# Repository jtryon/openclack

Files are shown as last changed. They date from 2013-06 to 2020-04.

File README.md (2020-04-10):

# OpenClack.TKL

## Preface
This repository contains all the source files needed to create a 87 key (tenkeyless) mechanical keyboard.</br>
In order to actually build this keep in mind you'll need access to the following.
* PCB fabrication.
* CNC, laser or waterjet cutting.
* Soldering iron and supplies.
* A source for your switches, stabilizers and electronic components.

## Licensing
Software in this project is licensed under the GPL.  See GPL.md</br>
Hardware in this project is licensed under the TAPR.  See TAPR.md

## Details
* Tenkeyless layout.
* Compatible with Cherry MX switches and both Cherry and Costar stabilizers.
* LED support for each key.
* Does not require a resistor for each LED.
* N-Key roll-over, no ghosting, 1 diode per switch.
* Firmware which allows for custom key mapping, macros, de-bouncing and LED control.
* Mini-B connector.
* Teensy 2.0++ controller.
Some images of a completed prototype based on the designs in this repo are in the "prototype_images" folder.
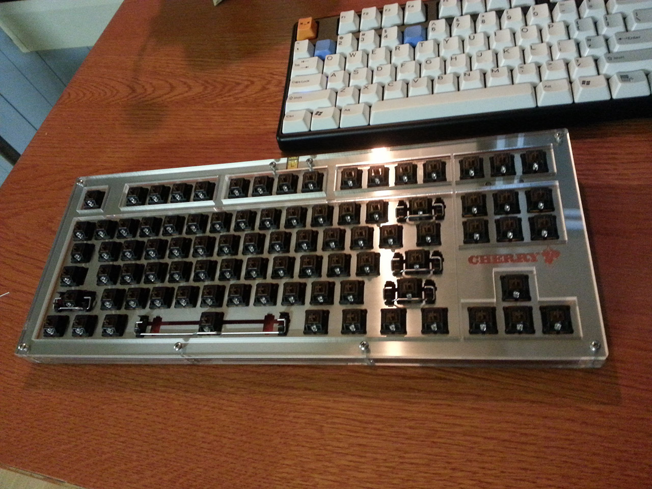
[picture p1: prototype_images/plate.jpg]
Plate
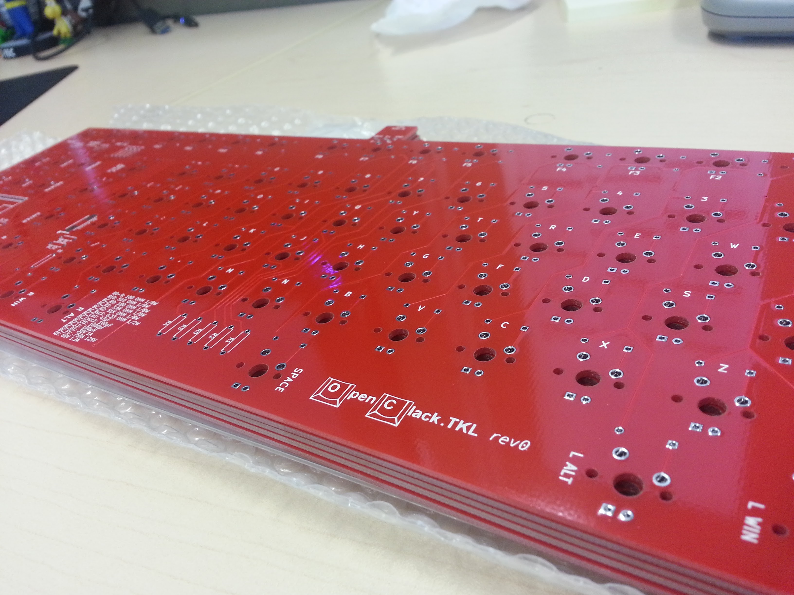
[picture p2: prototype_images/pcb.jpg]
PCB


## Project Files
* /dashkey/* - Firmware for the keyboard, codenamed DashKey.  Coded by SiberX.
* /fabrication/* - Final project files to be sent off and fabricated.
* /kicad_files/* - Kicad project.  Open the file "openclack-tkl.pro".
* /notes/* - Notes explaining the LED configuration, parts list, info on the boost converter, resistors.
* openclack.skp - Rough 3D render of the project (SketchUp).

## Instructions
There's currently no guide on how to do this but if you're technically inclined it should be doable with all the files contained herein.  If someone wants to develop a guide feel free to contribute!

## Loading Firmware
WIP

## Sources/Thanks
Thanks to the folks at http://deskthority.net/ for helping out when I had questions about measurements!</br>
Also a big thanks to BathroomEpiphanies.  Wouldn't have been able to do it without your amazing wiki.  [Check it out here!](http://deskthority.net/wiki/KiCAD_keyboard_PCB_design_guide)

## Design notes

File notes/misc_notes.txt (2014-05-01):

####Misc:

- Inserts - https://www.acklandsgrainger.com/AGIPortalWeb/WebSource/ProductDisplay/globalProductDetailDisplay.do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
 - Length: 3/16"
 - Drill Size: 3/16"
 - Thread Size: 4-40
- Screws - Up to you.  I'd recommend 4-40, Phillips countersunk.  You'd need to countersink the acrylic though (don't crack it!).
 - All screw holes are 0.2355" from edge (corner, center of intersecting lines) of case and are 0.045" in radius.
 - All insert holes are 0.2355" from edge (corner, center of intersecting lines) of case and are 0.0625" in radius.
- Layer cake style case notes (check out 3D_mockup.skp for a better idea of this)
 - 9mm for spacer
 - 1.524mm for plate
 - 10.524mm together
 - 5.0038mm from the top of the plate to the top of the pcb
 - 5.5202mm left
 - 1.66mm pcb
 - 3.8602mm clearance below pcb

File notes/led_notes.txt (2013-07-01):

10 sets of 8 leds each in series
1 odd set with 7 leds in series

power via boost converter and related componenents

http://hobby-hour.com/electronics/ledcalc.php
http://www.nomad.ee/micros/mc34063a/

teensy 2.0++ typical current draw 60.2 mA
boost converter efficiency is aprox 80%+

LED CALC Results (8 series):
Calculated resistance:	200O
Nearest lower 5% resistor:	180O
Nearest higher 5% resistor:	200O**
Power dissipated by the resistor:	9.8 mW
Recommended resistor Wattage:	1/8 W
Power consumed by the LEDs (PLED):	123.2 mW
Total power consumption (PTotal):	133 mW
Efficiency (PLED/PTotal) x 100 :	92.63 %

LED CALC Results (7 series):
Calculated resistance:	514.29O
Nearest lower 5% resistor:	510O*
Nearest higher 5% resistor:	560O
Power dissipated by the resistor:	25.2 mW
Recommended resistor Wattage:	1/8 W
Power consumed by the LEDs (PLED):	107.8 mW
Total power consumption (PTotal):	133 mW
Efficiency (PLED/PTotal) x 100 :	81.05 %

LED CALC Results (individual indicator LEDs):
Calculated resistance:	2.8kO
Nearest lower 5% resistor:	2.7kO*
Nearest higher 5% resistor:	3kO
Power dissipated by the resistor:	2.8 mW
Recommended resistor Wattage:	1/8 W
Power consumed by the LED (PLED):	2.2 mW
Total power consumption (PTotal):	5 mW
Efficiency (PLED/PTotal) x 100 :	44 %

MC34063A CALC Results:
Ct=626 pF		(above 700 pf cap)
Ipk=773 mA
Rsc=0.388 Ohm   (rsc<= 0.3 Ohm resistor, 1/4 watt resistor)
Lmin=81 uH      (minimum inductor, 100mh)
Co=39 uF		(47 mf cap for here, supports 25v+)
R=180 Ohm
R1=3.6k R2=51k (18.96V)
http://i.imgur.com/qerIIto.png
1N5818, 1N5819 schottky diode
//All otherwise unmentioned resistors can be 1/8th watt//

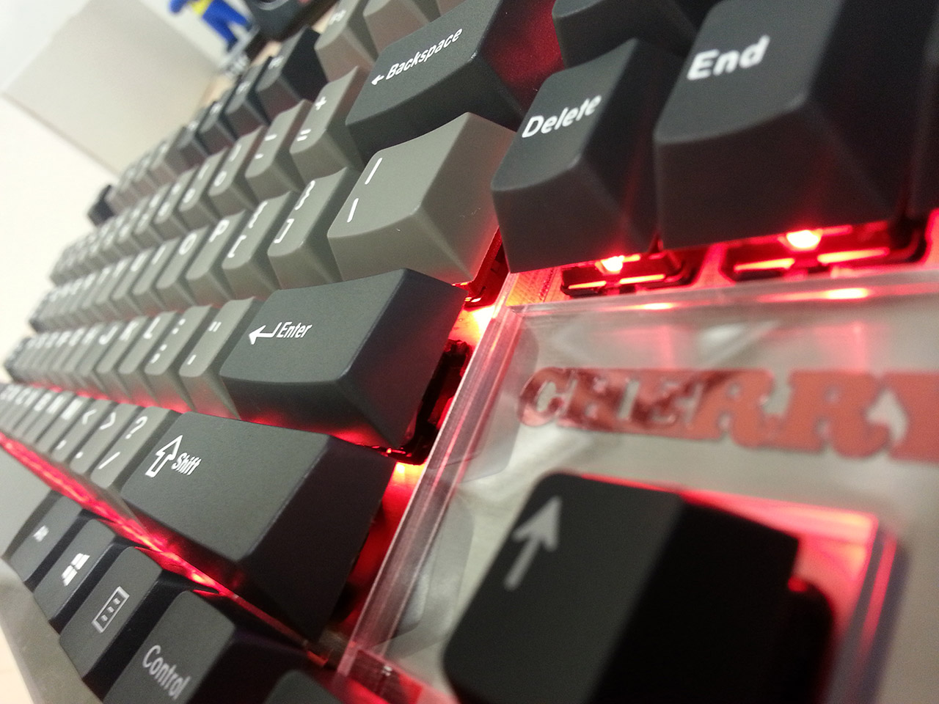
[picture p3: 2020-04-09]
prototype_images/closeup.jpg

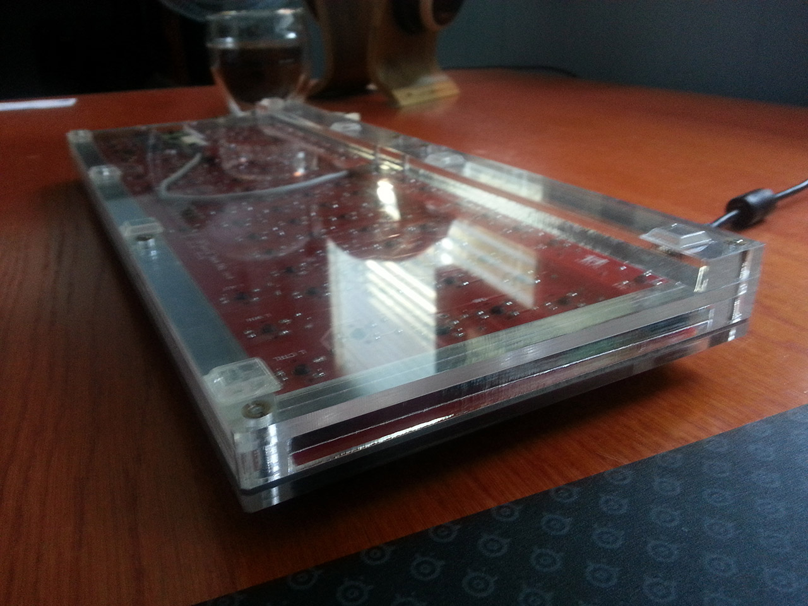
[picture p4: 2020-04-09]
prototype_images/acrylic_back.jpg

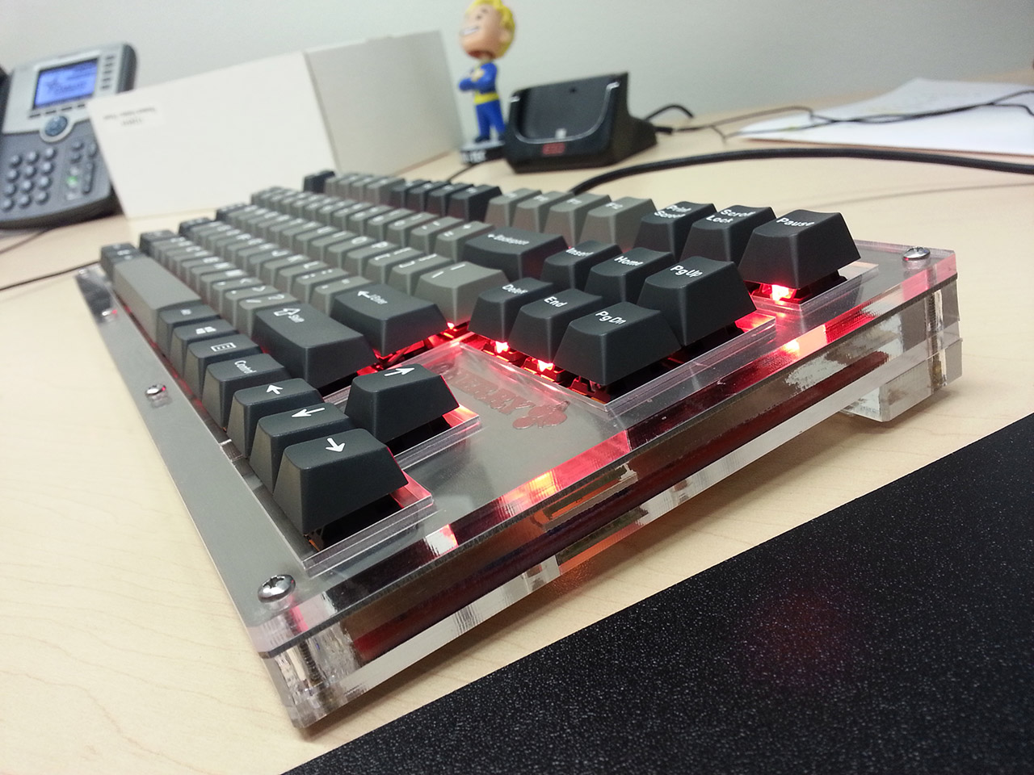
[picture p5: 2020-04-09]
prototype_images/acrylic_top.jpg

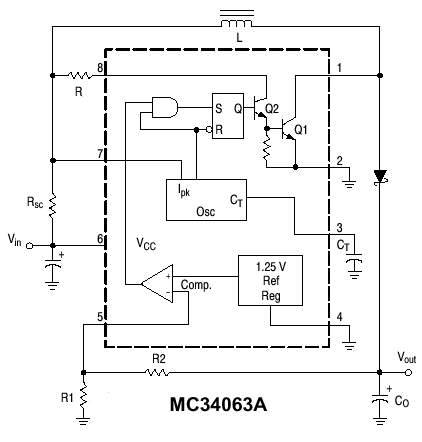
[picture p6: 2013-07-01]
notes/MC34063A_diagram.png

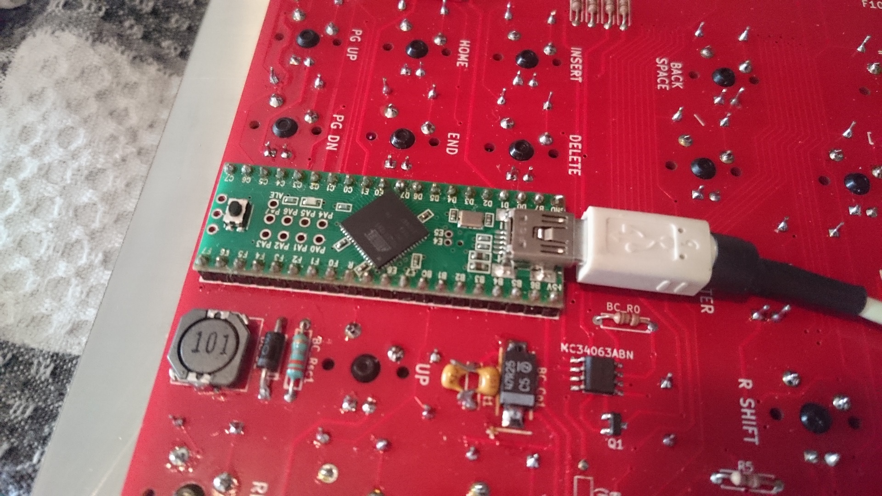
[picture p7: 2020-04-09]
prototype_images/teensy1.JPG

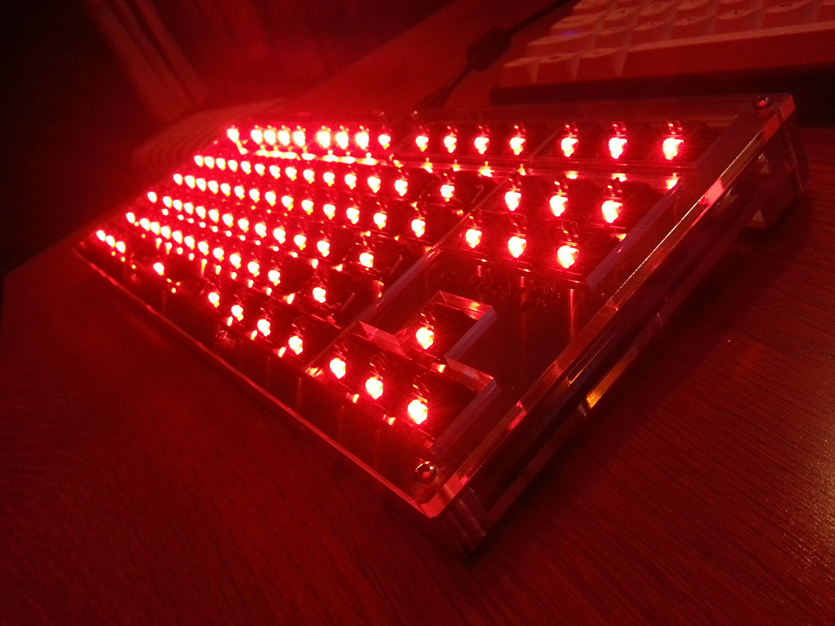
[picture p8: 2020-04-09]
prototype_images/leds.jpg

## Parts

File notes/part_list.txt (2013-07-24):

Quantity Sug.		Okay?		KiCad Module			Kicad Ref				URL																						Thickness	Kicad Footprint
=============================================================================================================================================================================================================================
1					Y			BC_Co1					CP1						http://www.digikey.ca/product-detail/en/TR3D476K025C0150/718-1525-1-ND/1860000          3.10mm		TantalC_SizeD_EIA-7343_HandSoldering_RevA_28Aug2012
1					Y			BC_Ct1					CP1						http://www.digikey.ca/product-detail/en/C410C102K1R5TA7200/399-4450-1-ND/818307         2.54mm      CP_6mm
1					Y			BC_Cvcc1				CP1						http://www.digikey.ca/product-detail/en/RVA0J101MNG/493-6670-1-ND/3465996               3.00mm      TantalC_SizeD_EIA-7343_HandSoldering_RevA_28Aug2012
1					Y			BC_L1					INDUCTOR				http://www.digikey.ca/product-detail/en/SCRH103R-101/595-1406-1-ND/2771443              3.10mm      SCRH103R
1					Y			BC_R0					RESISTOR				http://www.digikey.ca/product-detail/en/CF18JT180R/CF18JT180RCT-ND/2022724              1.70mm 		R3
1					Y			BC_R1					RESISTOR				http://www.digikey.ca/product-detail/en/CF18JT3K60/CF18JT3K60CT-ND/2022755              1.70mm      R3
1					Y			BC_R2					RESISTOR				http://www.digikey.ca/product-detail/en/CF18JT51K0/CF18JT51K0CT-ND/2022783              1.70mm      R3
1					Y			BC_Rsc1					RESISTOR				http://www.digikey.ca/product-detail/en/1622602-1/A105966CT-ND/3477549                  2.30mm      R4
1					Y			BC_D1					DIODE					http://www.digikey.ca/product-detail/en/1N5818-T/1N5818DICT-ND/190657                   2.72mm      DO-41
1					Y			VREG1					MC34063ABN				http://www.digikey.ca/product-detail/en/MC34063ACD-TR/497-7850-1-ND/1883654             1.75mm      so-8
1					Y			Q1						FET_N					http://www.digikey.ca/product-detail/en/IRLML2060TRPBF/IRLML2060TRPBFCT-ND/2271917		1.12mm      SOT23
2 (1 backup)		Y			BC_F1					FUSE					http://www.digikey.ca/product-detail/en/0251.750MXL/F2353-ND/776753						3.18mm		MQ750 (double check size)
100					Y			D						DIODE(is an LED tho)	http://www.digikey.ca/product-detail/en/OVLBR4C7/365-1175-ND/827111									Part of the switches
100					Y			Dx:x					DIODE					http://www.digikey.ca/product-detail/en/1N4148,113/568-1360-1-ND/763357								D3
10					Y			R0-9					RESISTOR				http://www.digikey.ca/product-detail/en/CF18JT180R/CF18JT180RCT-ND/2022724							R3
1					Y			R10						RESISTOR				http://www.digikey.ca/product-detail/en/CF18JT510R/CF18JT510RCT-ND/2022735							R3
4					Y			D0,D1					LED						http://www.digikey.ca/product-detail/en/OVLBY4C7/365-1176-ND/827112									LED-3MM
2					Y			LED_R0,LED_R1			RESISTOR				http://www.digikey.ca/product-detail/en/CF18JT2K70/CF18JT2K70CT-ND/2022752							R3
1					Y			USB-MINI-B				CON1					http://www.digikey.ca/product-detail/en/USB-M26FTR/ED2992CT-ND/2677756								conn_usb_B_mini_smd
4					Y			N/A						N/A						http://www.digikey.ca/product-detail/en/PRPC040SAAN-RC/S1011EC-40-ND/2775214

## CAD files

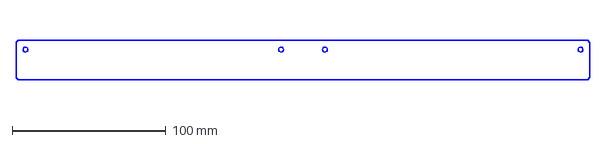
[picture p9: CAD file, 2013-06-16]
dxf_plots/acrylic_4.dxf
373.0 x 25.4 mm

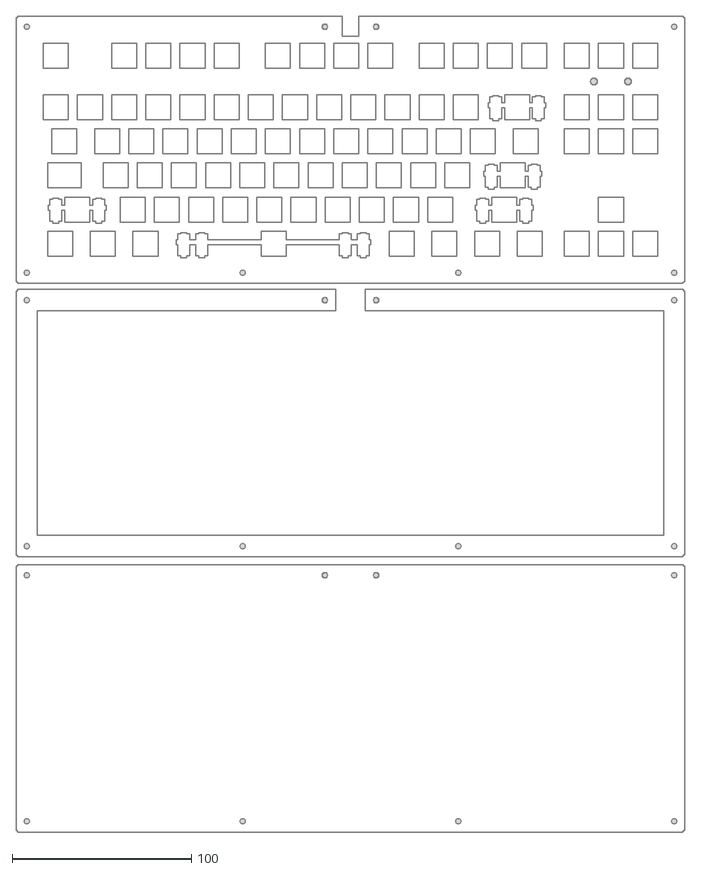
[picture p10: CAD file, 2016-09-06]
fabrication/prototype b/openclack-tkl-case-and-plate.dxf
373.0 x 455.0

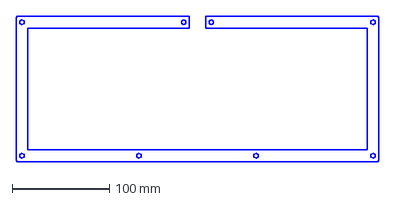
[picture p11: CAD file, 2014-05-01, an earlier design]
fabrication/prototype a/case/acrylic_1.dxf
373.0 x 149.1 mm

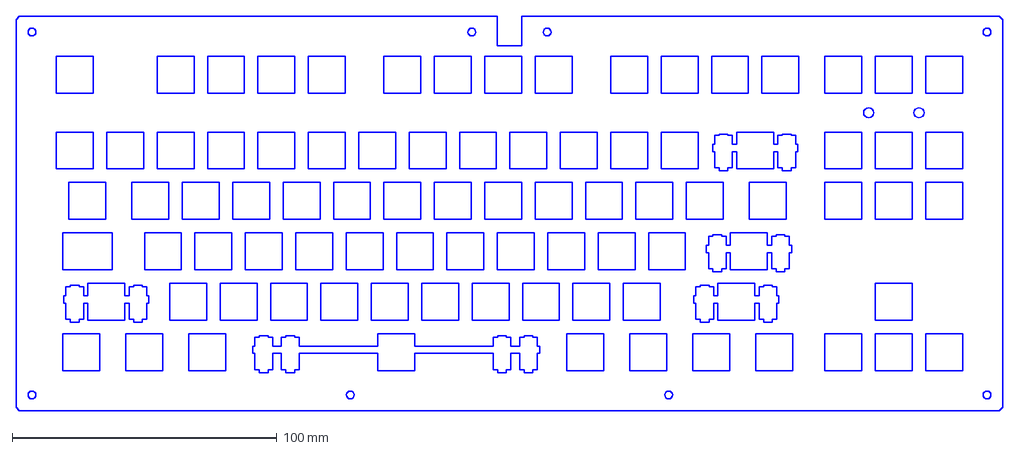
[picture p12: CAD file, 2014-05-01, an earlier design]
fabrication/prototype a/plate/plate.dxf
373.0 x 149.1 mm

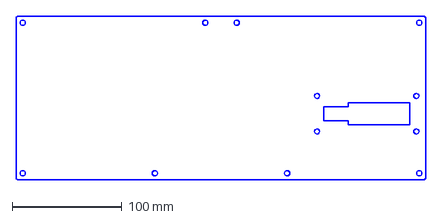
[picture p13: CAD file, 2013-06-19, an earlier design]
fabrication/prototype a/case/acrylic_2.dxf
373.0 x 149.1 mm

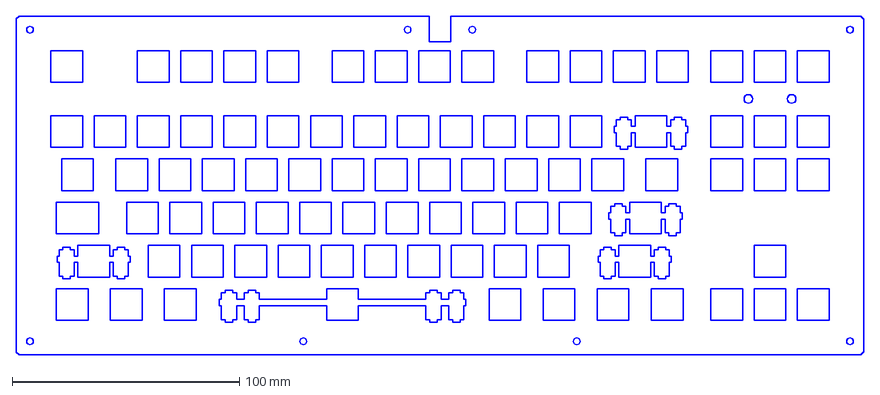
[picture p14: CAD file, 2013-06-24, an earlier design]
fabrication/prototype a/plate/plate_modded_4_waterjet_cut.dxf
373.0 x 149.1 mm

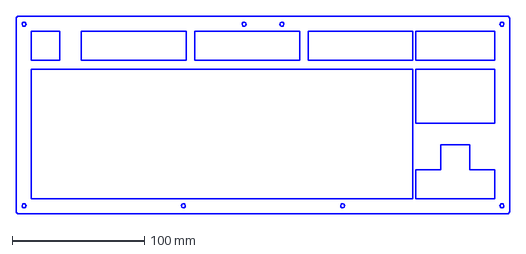
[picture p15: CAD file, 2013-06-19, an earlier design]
fabrication/prototype a/case/acrylic_0.dxf
373.0 x 149.1 mm

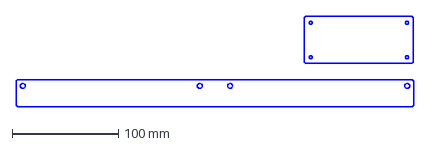
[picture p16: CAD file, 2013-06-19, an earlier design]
fabrication/prototype a/case/acrylic_3.dxf
373.0 x 84.8 mm

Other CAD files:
openclack.skp

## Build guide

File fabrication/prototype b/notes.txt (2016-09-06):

This version of the project is a simple and lightweight case you can create with a laser cutter.
All units are in mm.

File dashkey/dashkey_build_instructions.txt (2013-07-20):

1. Grab a copy of WinAVR:
http://sourceforge.net/projects/winavr/files/
And install it.

2. Grab a copy of the eclipse IDE (you should get the C/C++ edition if you want minimum grief):
http://www.eclipse.org/downloads/
Or set up another development environment of your choice

3. Get the latest avr-eclipse:
http://sourceforge.net/projects/avr-eclipse/files/avr-eclipse%20beta%20versions/
And add it to your eclipse installation. A helpful guide can be found here:
http://avr-eclipse.sourceforge.net/wiki/index.php/Plugin_Download

4. Grab the latest build of LUFA:
http://www.fourwalledcubicle.com/LUFA.php (2013-03-03 as of this writing)
And extract it to a folder.

5. Grab the latest build of dashkey out of the openclack github: (if you don't have it already)
https://github.com/toastfox/openclack

6. Open the dashkey project in eclipse

7. Edit the makefile to provide a valid LUFA_PATH. While you're in here, be sure to set valid MCU, F_CPU, etc.. values

8. Because eclipse sucks, you'll need to ignore a couple of their code analysis tools. To do so, open the project properties, go to "C/C++ General" then "Code Analysis". Set the radio button to "Use project settings", then uncheck "Symbol is not resolved", "Type cannot be resolved" and "Field cannot be resolved" down at the bottom

7. Attempt to build, cry if it fails, fix errors

8. Assuming no errors, grab the resulting dashkey.hex and flash it to your keyboard controller

9. Optionally, generate an eeprom file and flash that too (if you want a custom keyboard map)

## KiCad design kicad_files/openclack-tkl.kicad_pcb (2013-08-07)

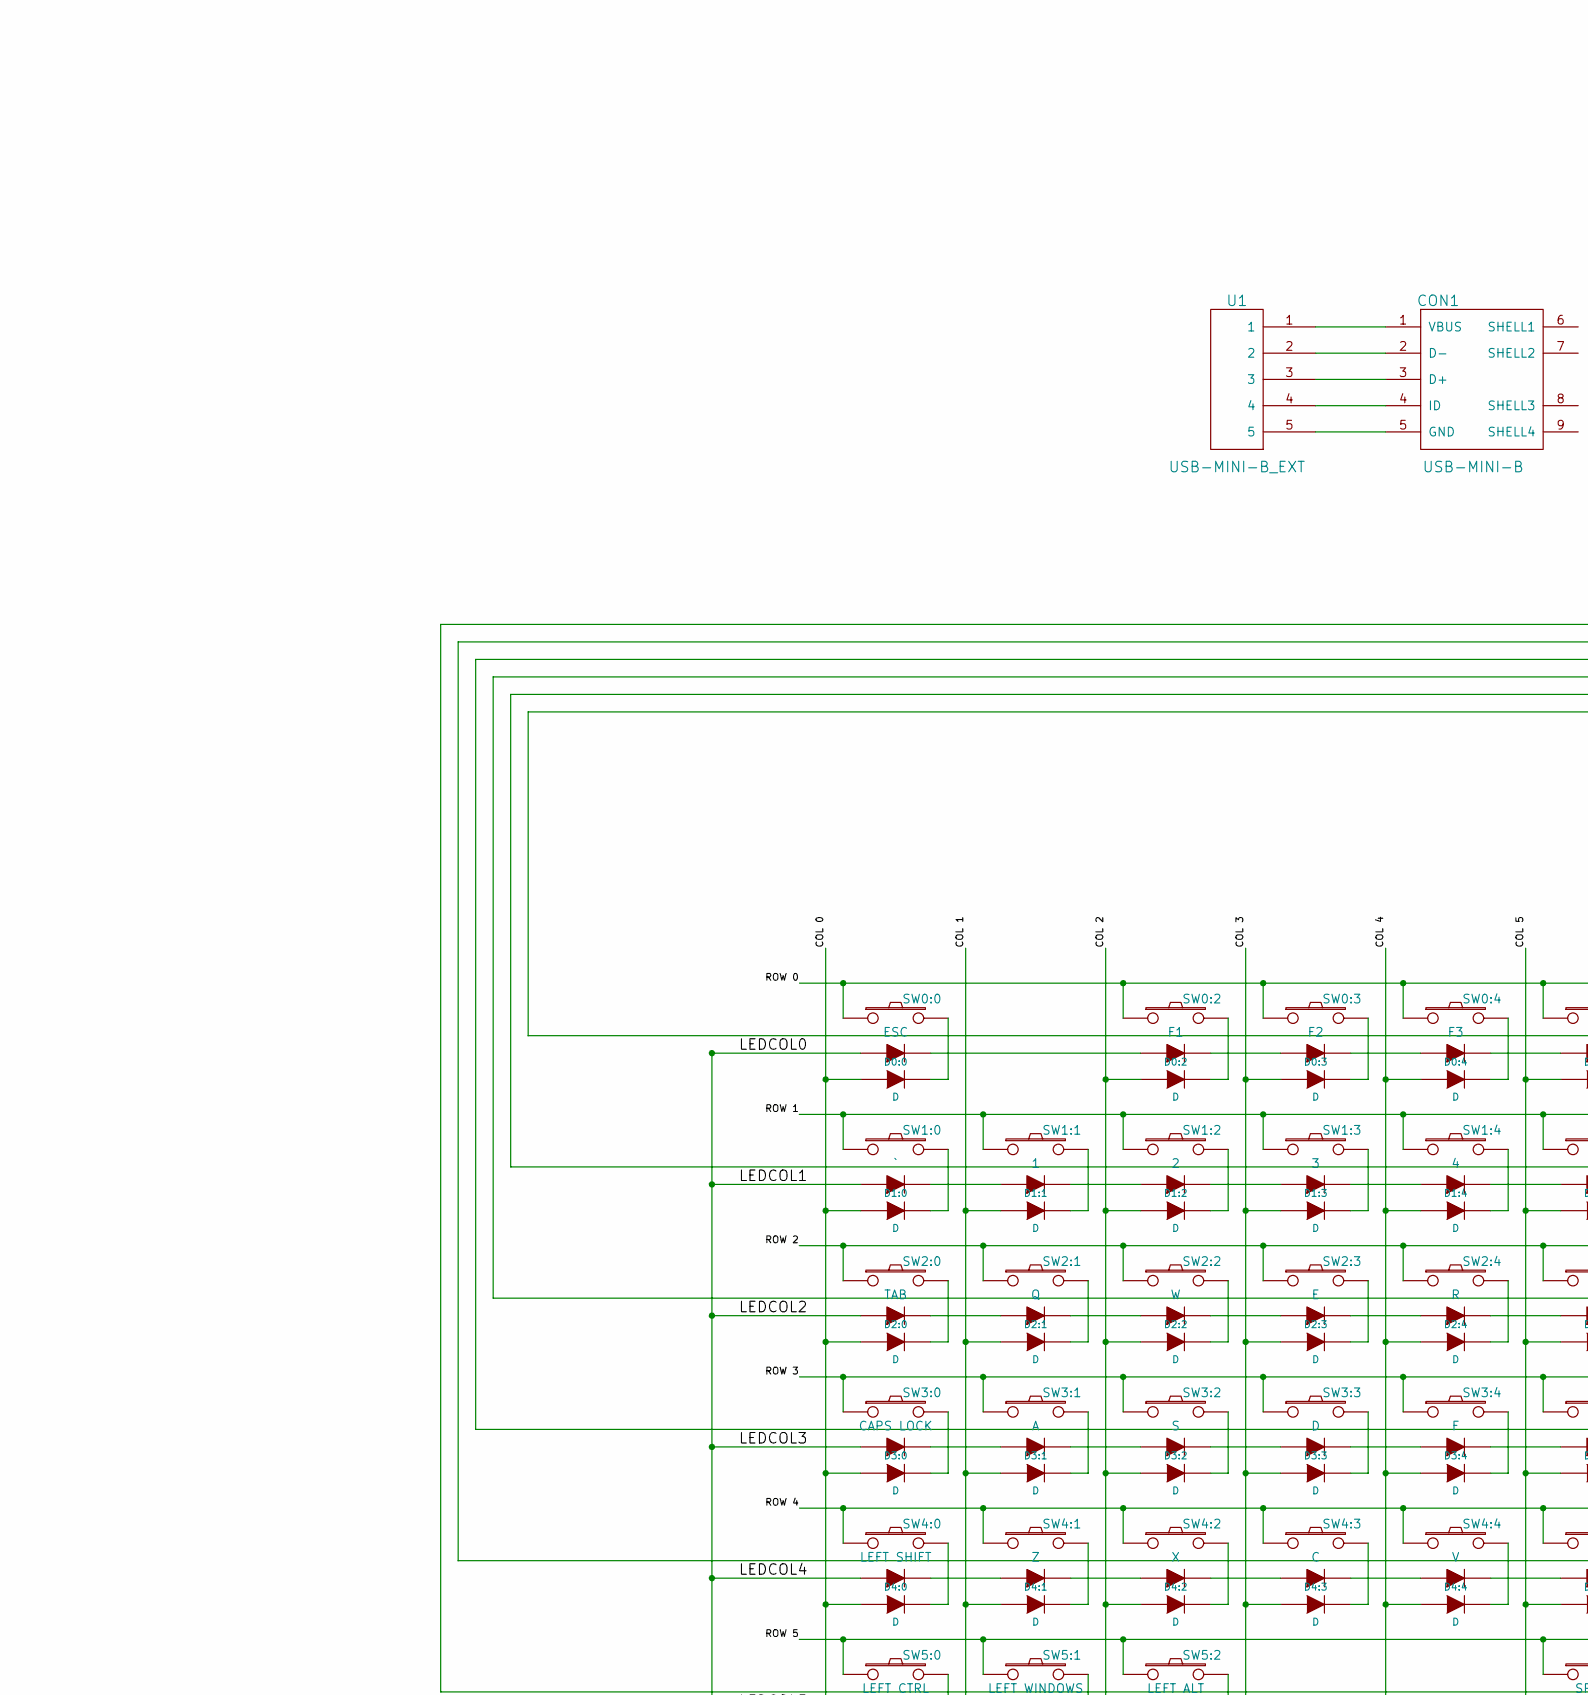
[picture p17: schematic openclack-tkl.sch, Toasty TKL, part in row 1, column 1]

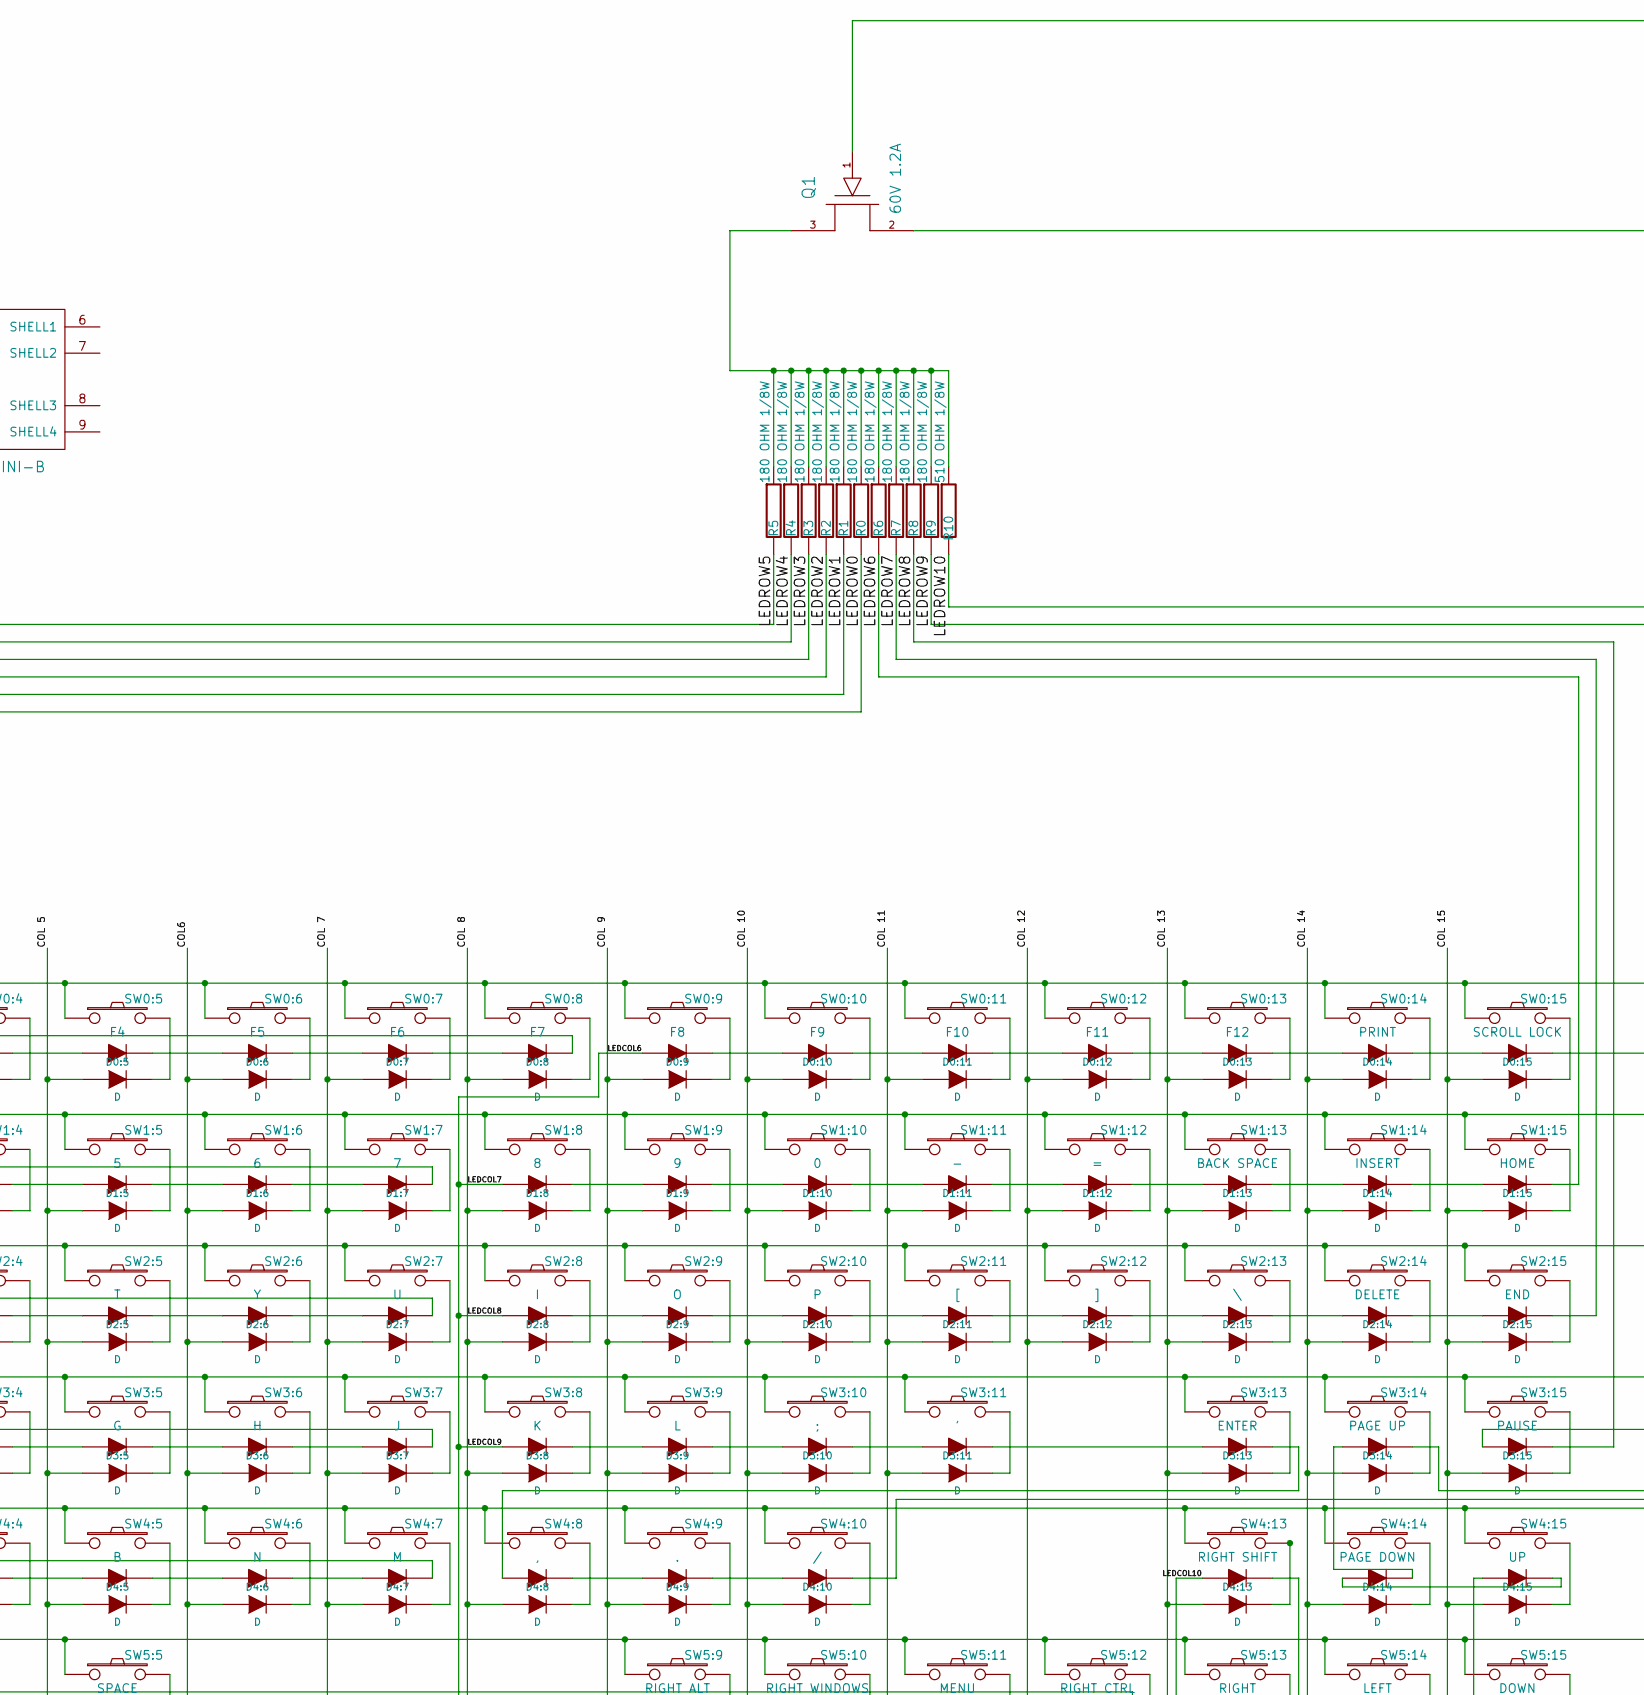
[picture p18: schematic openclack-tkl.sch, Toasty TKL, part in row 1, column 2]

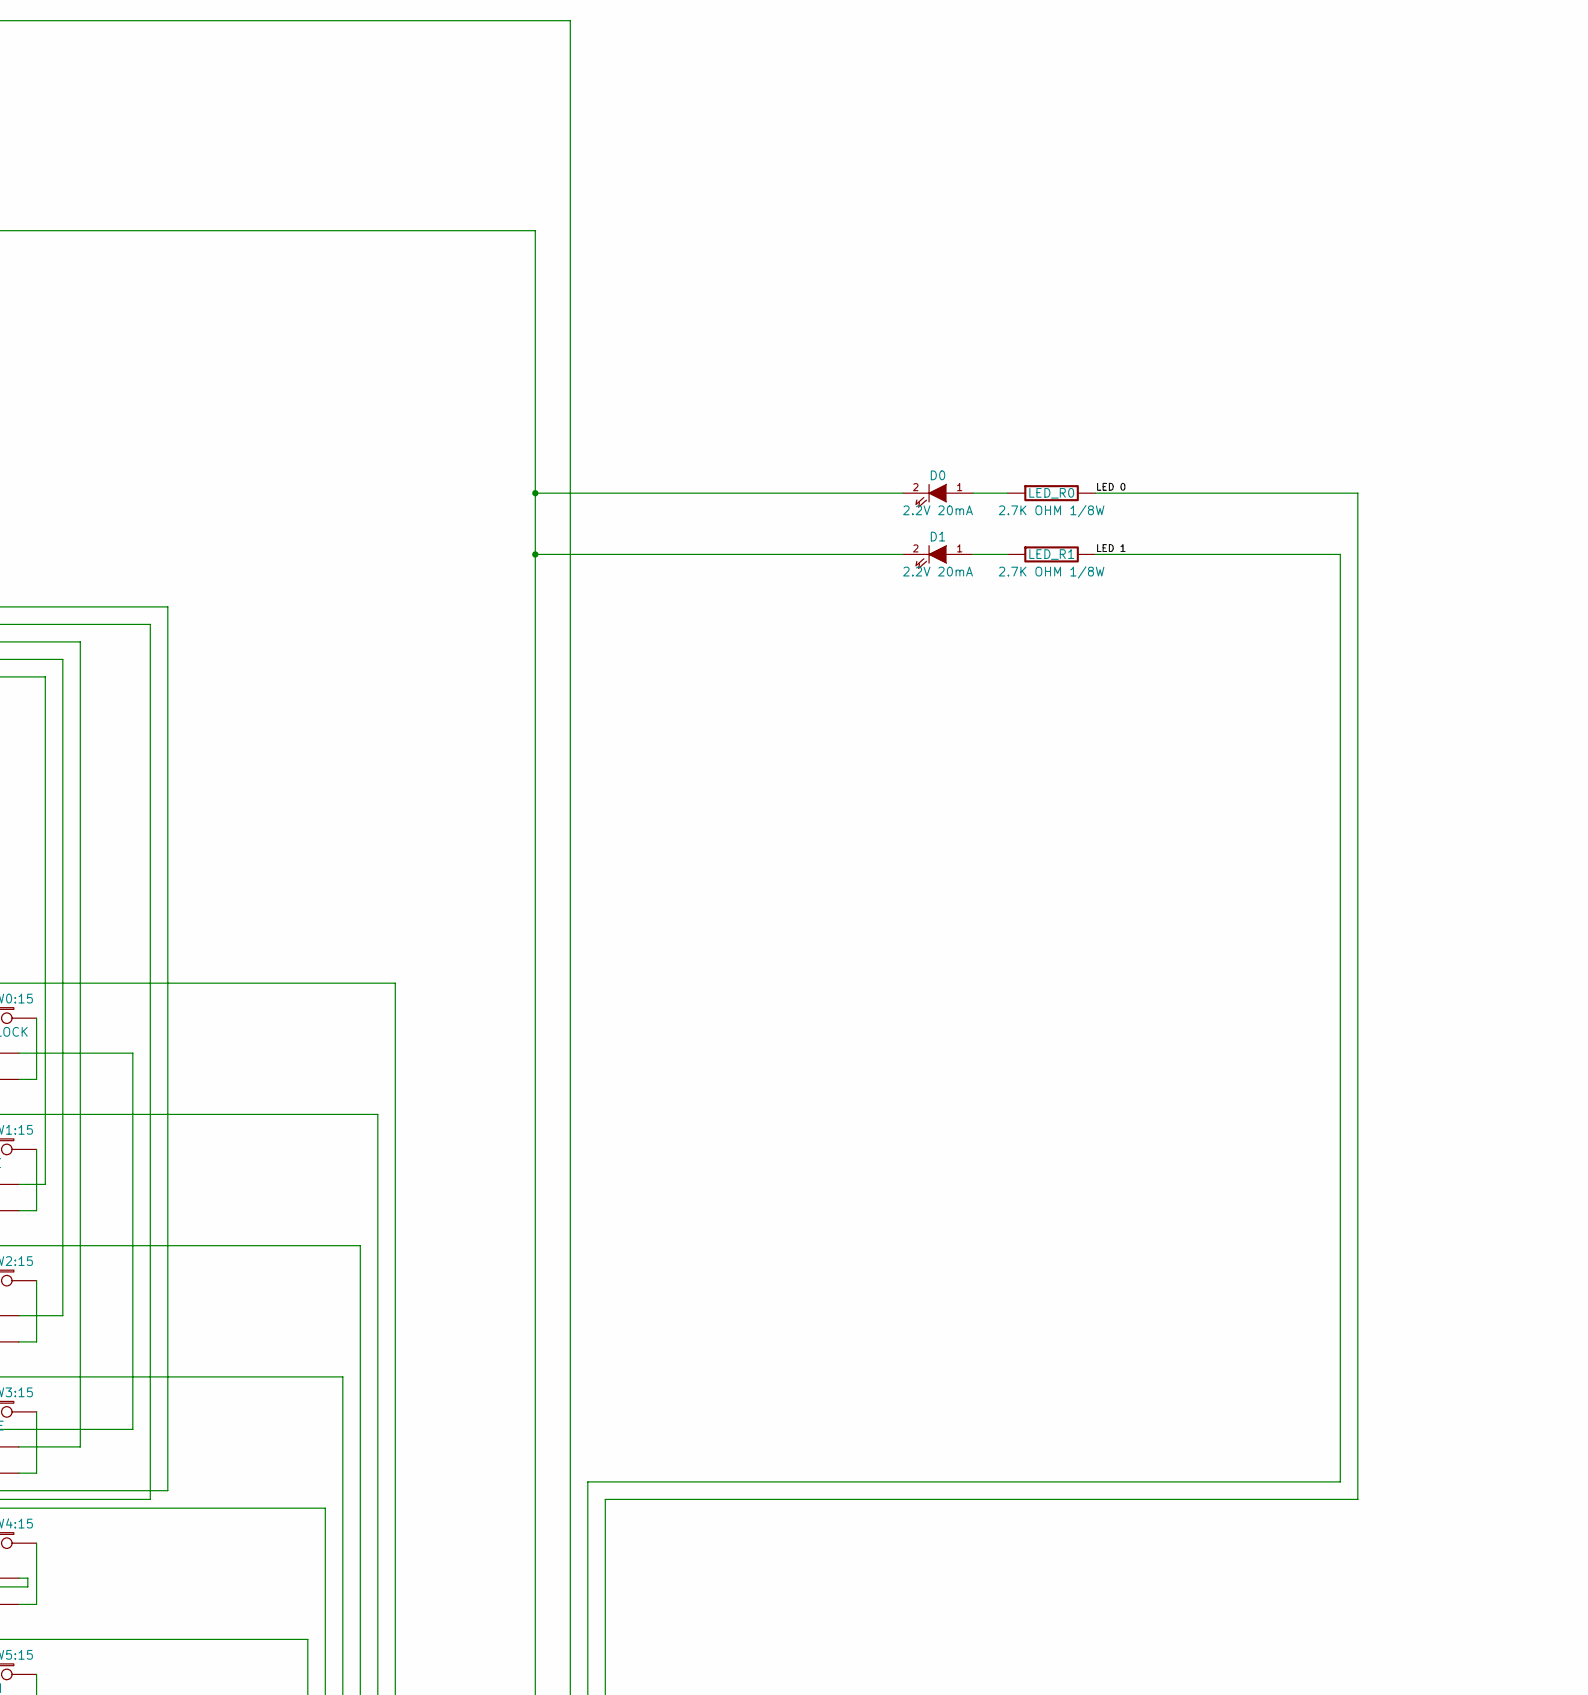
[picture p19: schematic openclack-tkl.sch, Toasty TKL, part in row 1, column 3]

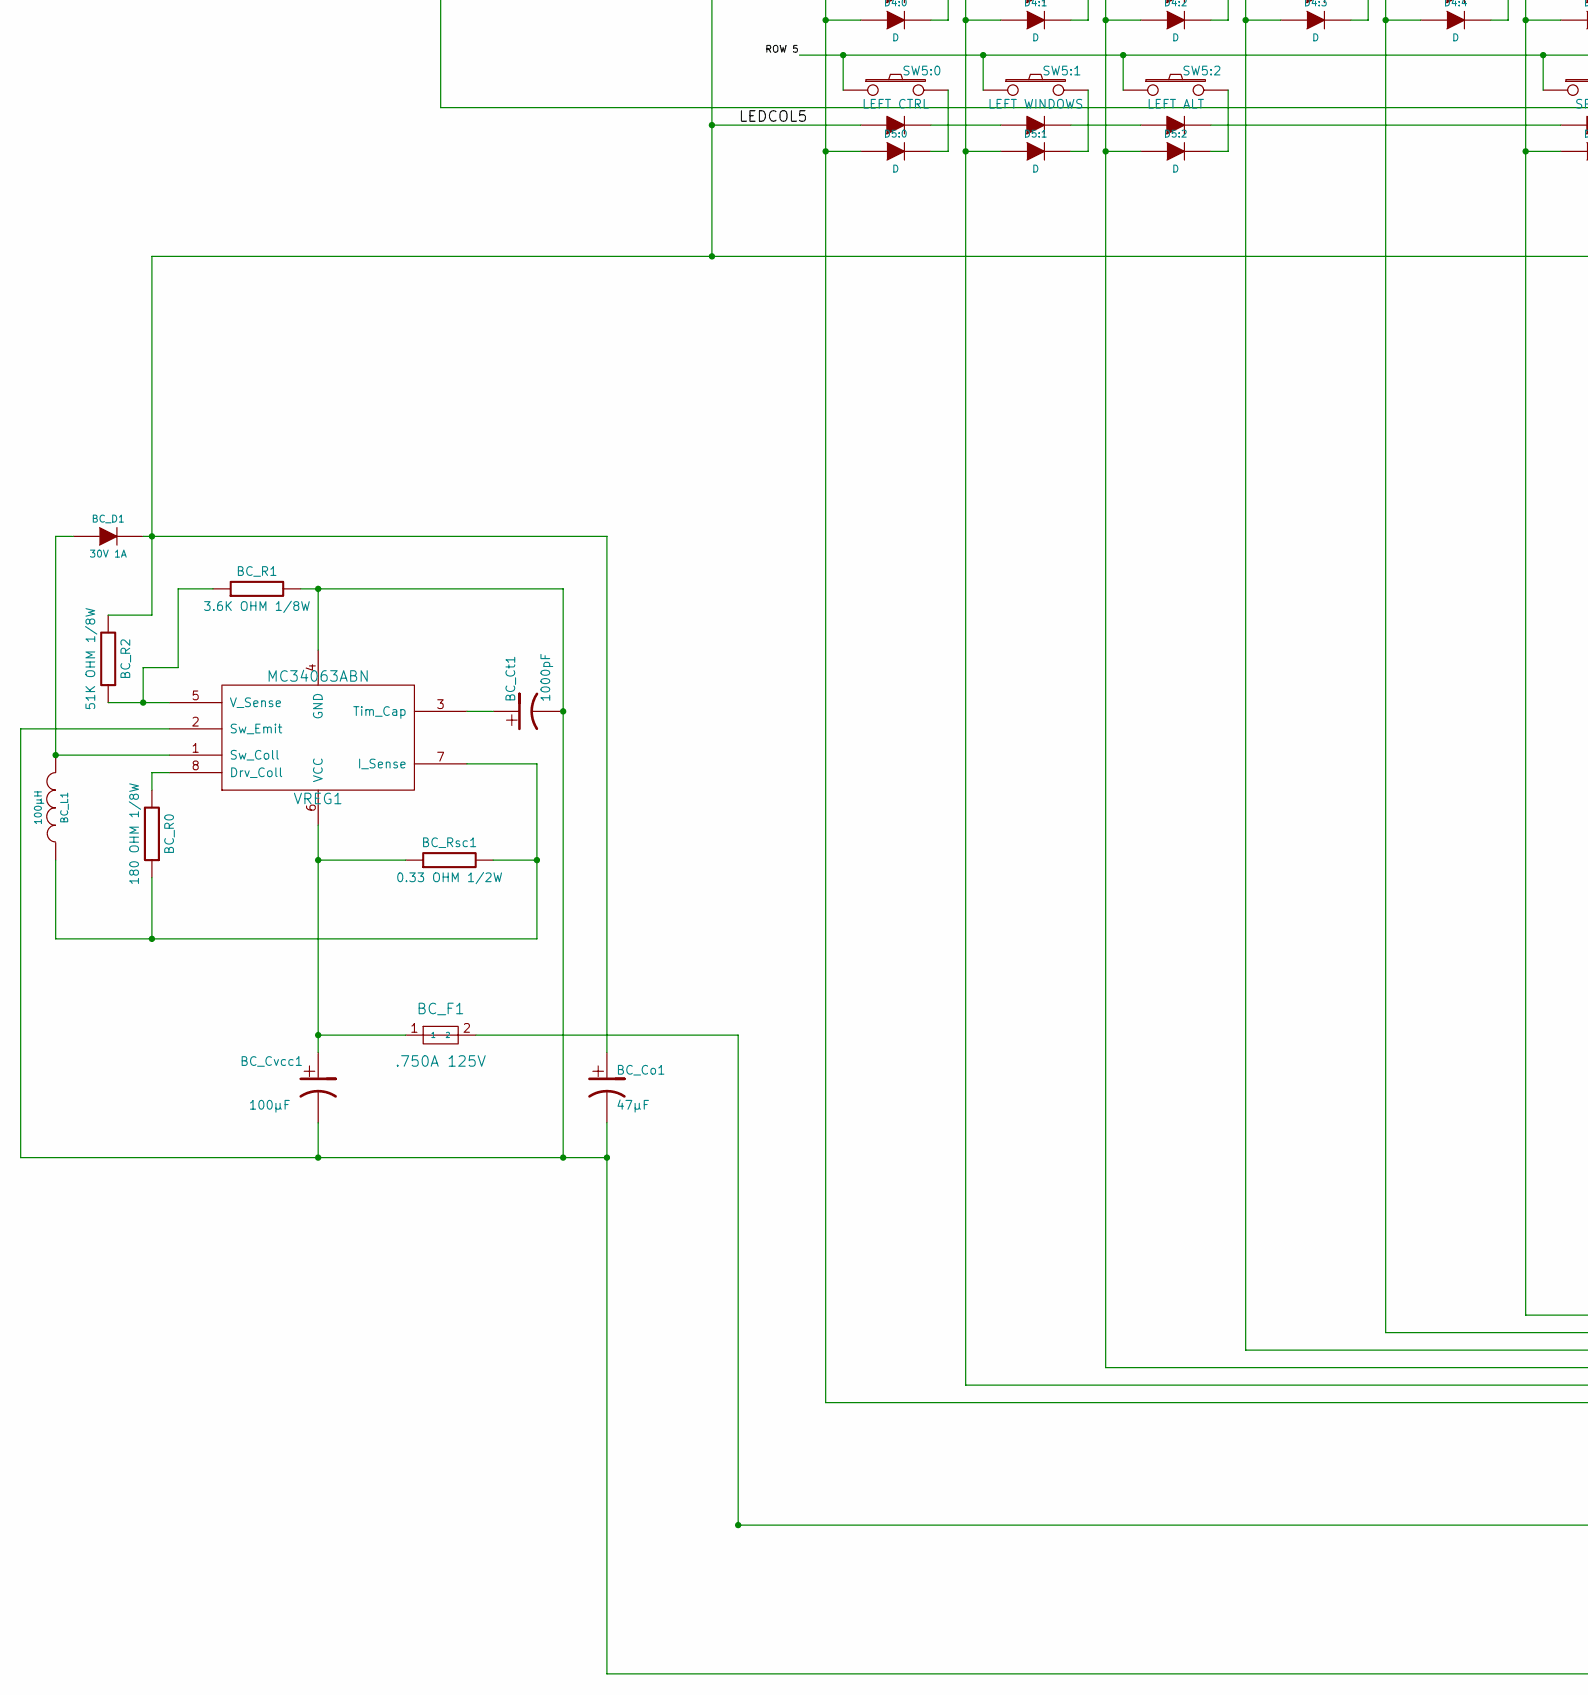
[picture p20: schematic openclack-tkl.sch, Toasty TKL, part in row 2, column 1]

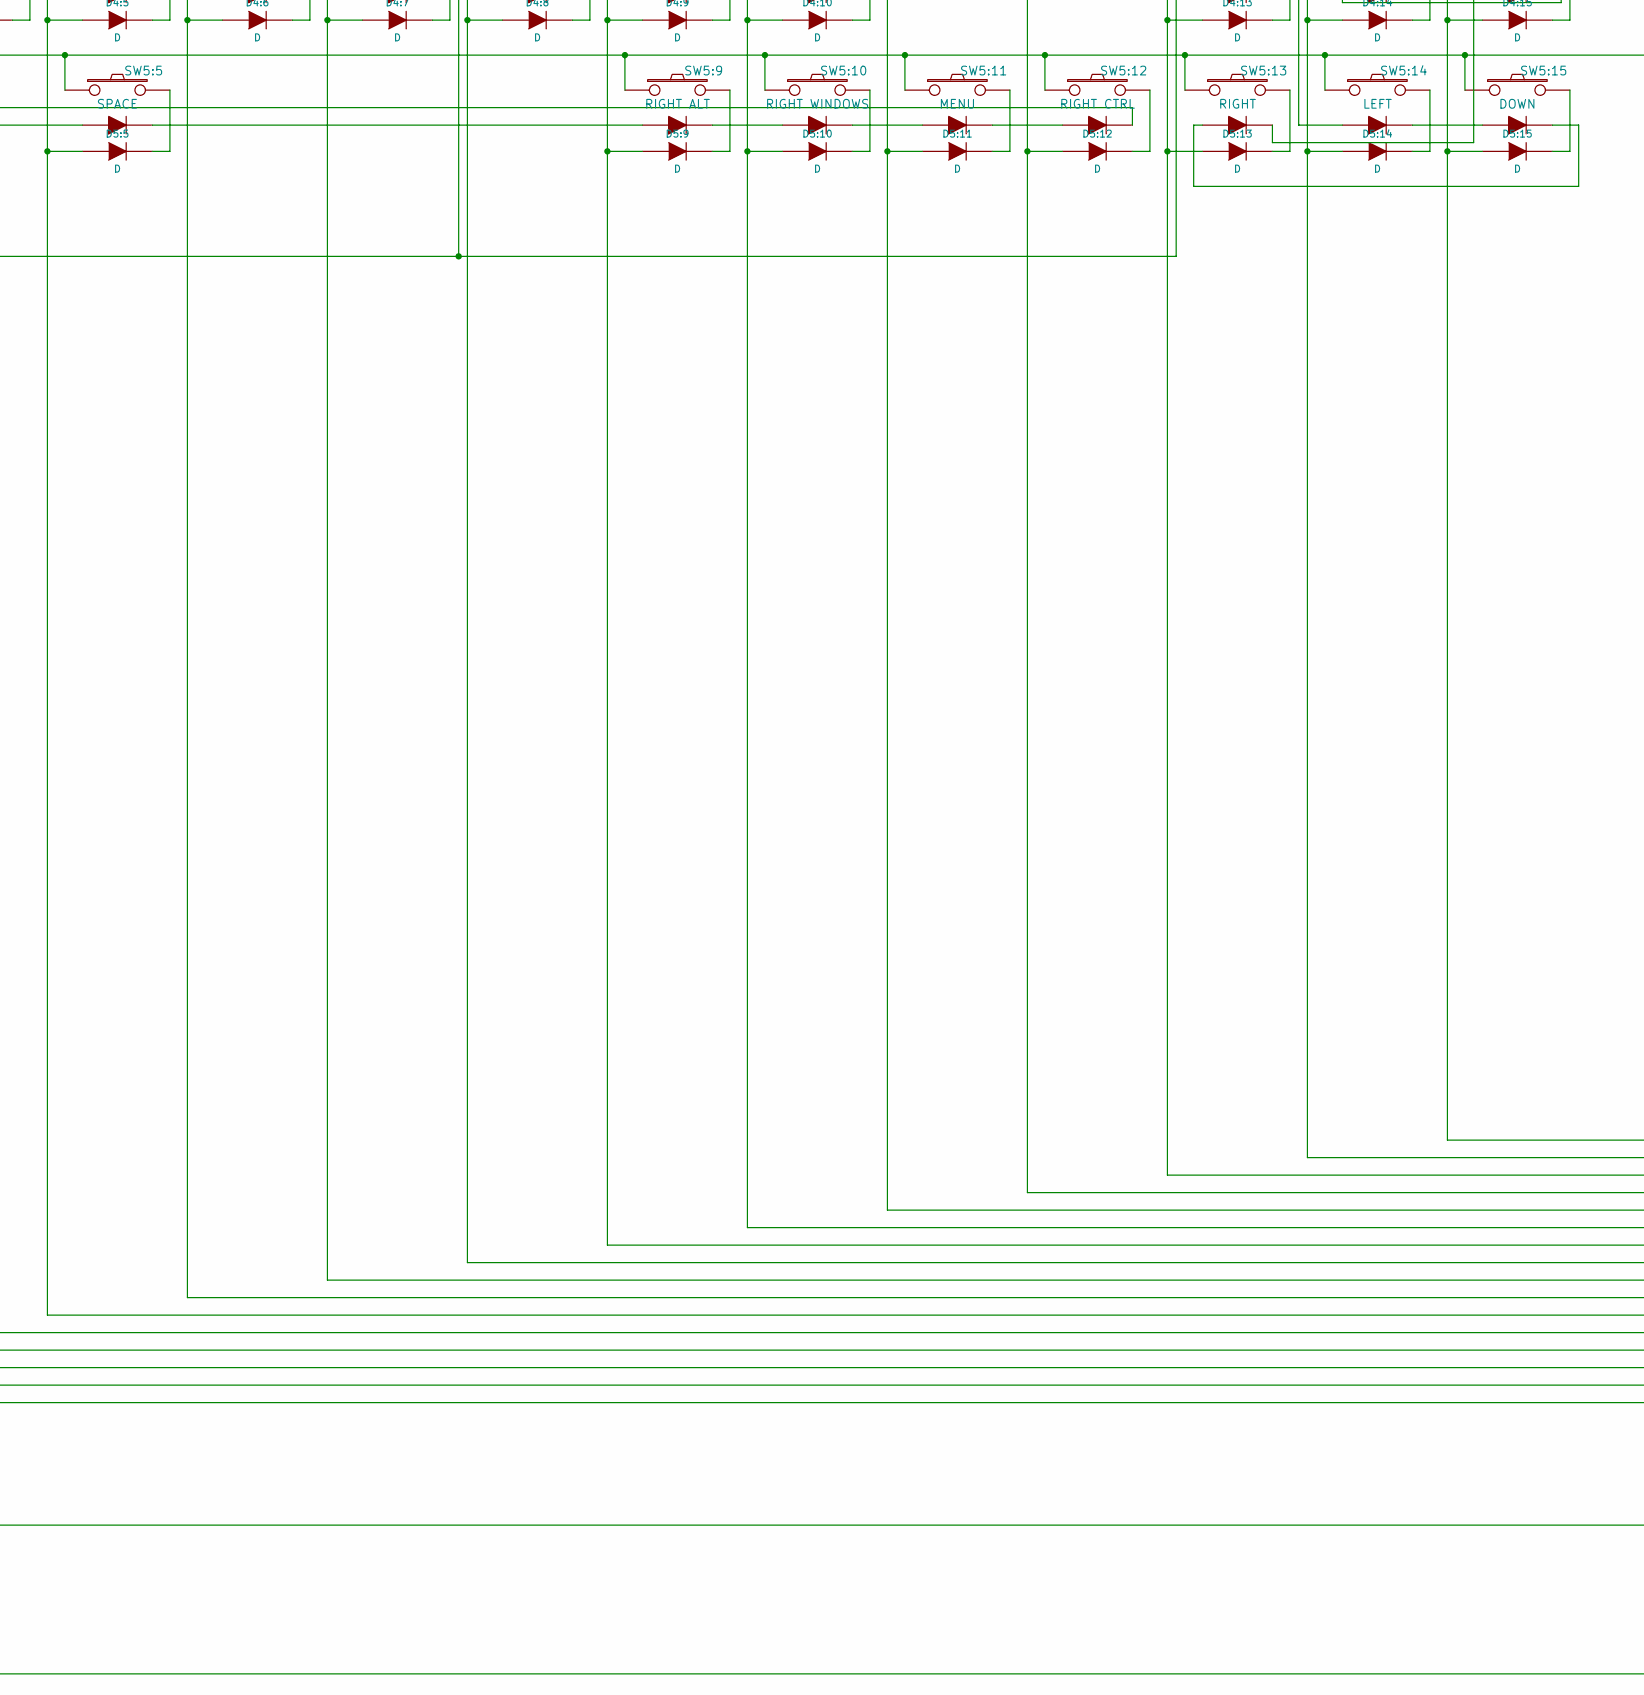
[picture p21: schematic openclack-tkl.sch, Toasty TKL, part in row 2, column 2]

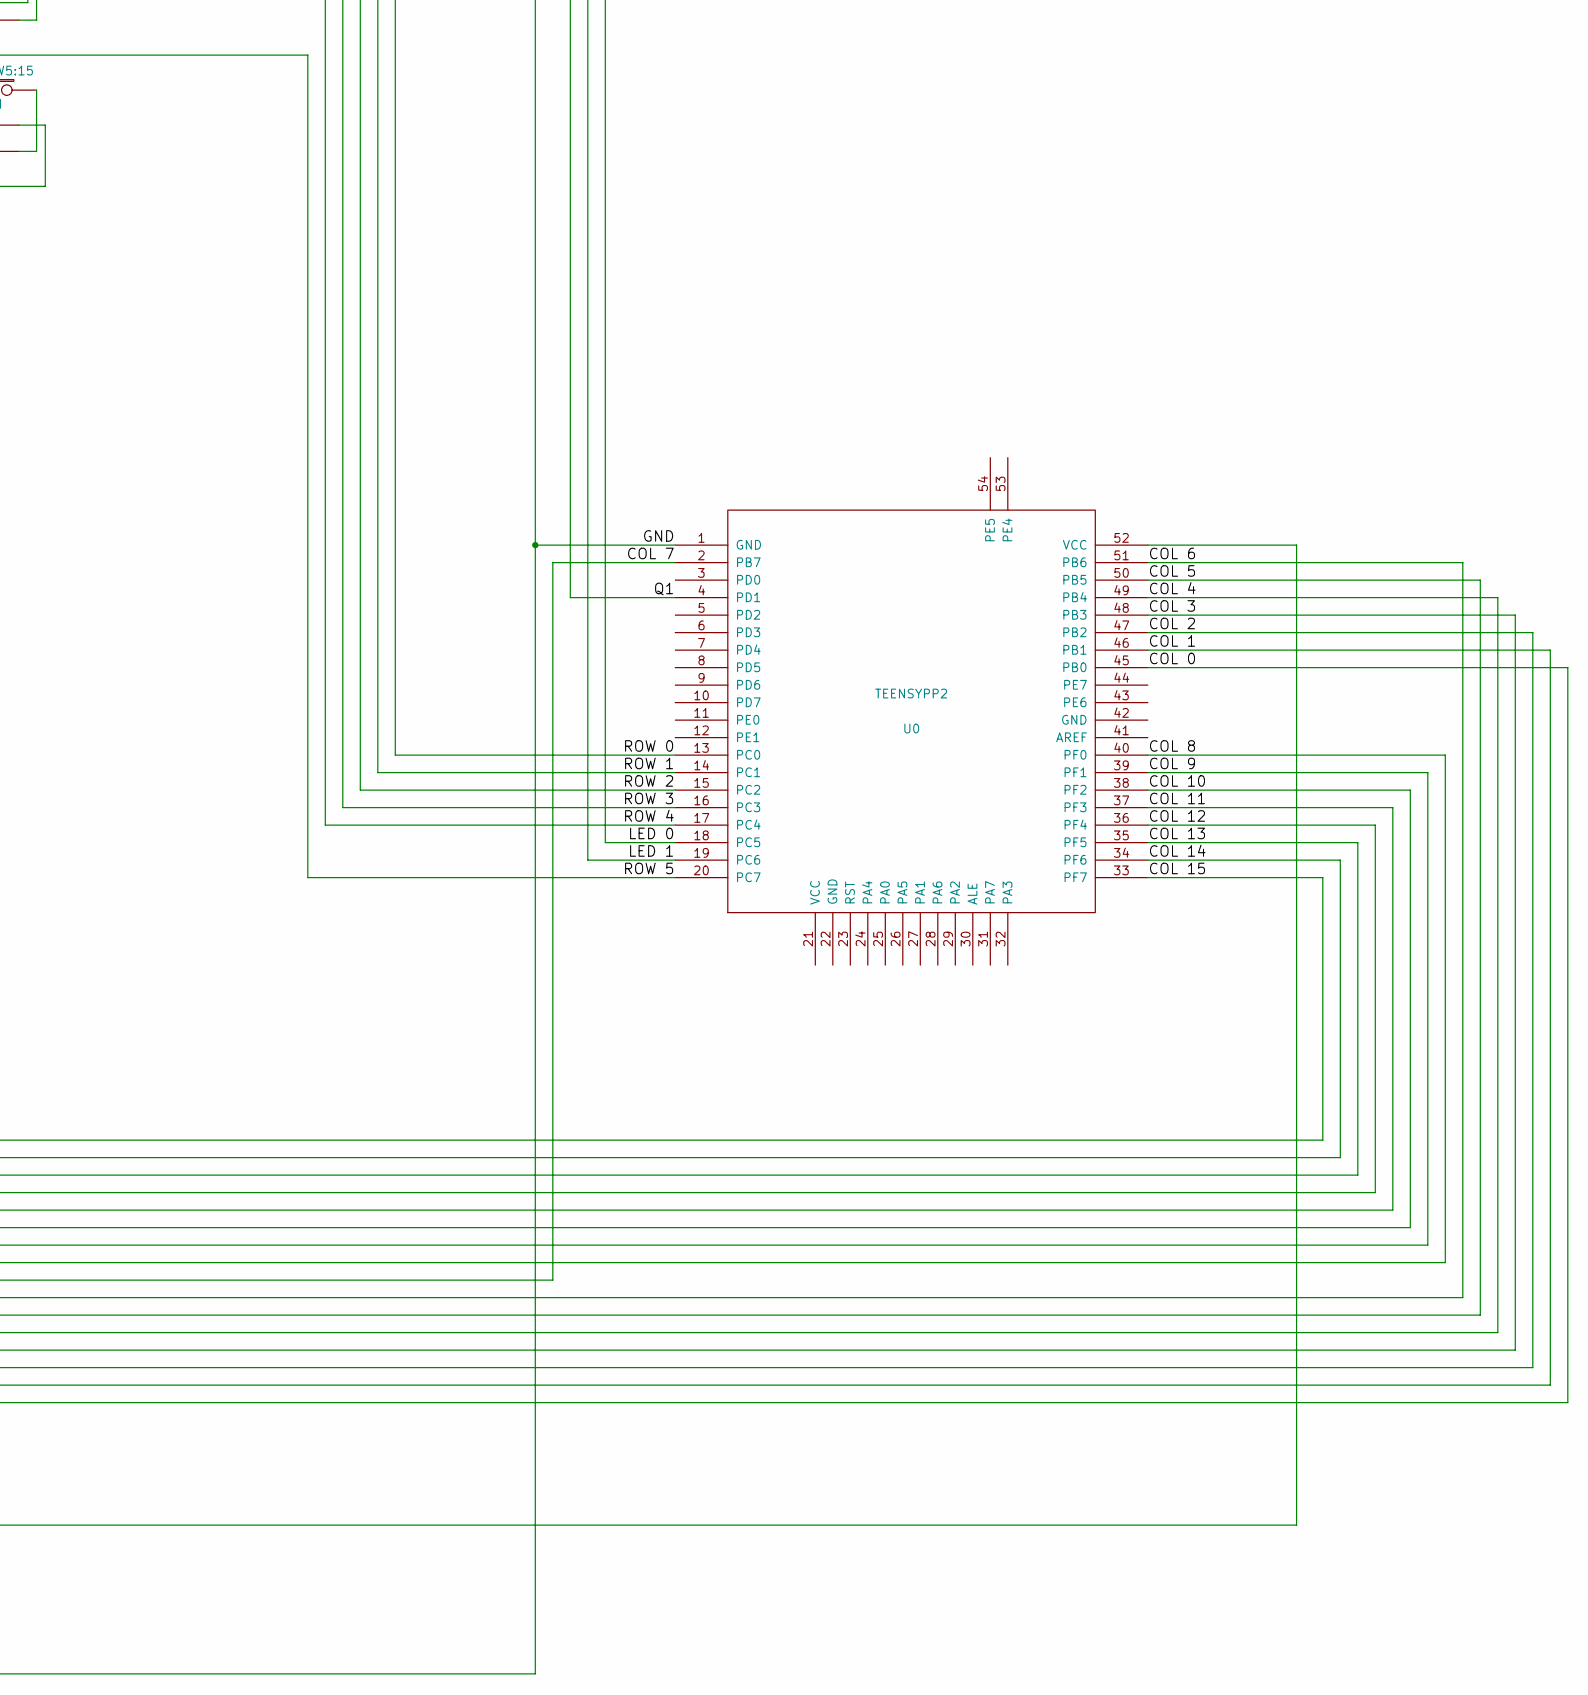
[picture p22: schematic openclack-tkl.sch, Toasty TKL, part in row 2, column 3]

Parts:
BC_Co1: 47µF
BC_Ct1: 1000pF
BC_Cvcc1: 100µF
BC_D1: 30V 1A
BC_F1: .750A 125V
BC_L1: 100µH
BC_R0: 180 OHM 1/8W
BC_R1: 3.6K OHM 1/8W
BC_R2: 51K OHM 1/8W
BC_Rsc1: 0.33 OHM 1/2W
CON1: USB-MINI-B
D0, D1: 2.2V 20mA
D0:0, D0:2, D0:3, D0:4, D0:5, D0:6, D0:7, D0:8, D0:9, D0:10, D0:11, D0:12, D0:13, D0:14, D0:15, D1:0, D1:1, D1:2, D1:3, D1:4, D1:5, D1:6, D1:7, D1:8, D1:9, D1:10, D1:11, D1:12, D1:13, D1:14, D1:15, D2:0, D2:1, D2:2, D2:3, D2:4, D2:5, D2:6, D2:7, D2:8, D2:9, D2:10, D2:11, D2:12, D2:13, D2:14, D2:15, D3:0, D3:1, D3:2, D3:3, D3:4, D3:5, D3:6, D3:7, D3:8, D3:9, D3:10, D3:11, D3:13, D3:14, D3:15, D4:0, D4:1, D4:2, D4:3, D4:4, D4:5, D4:6, D4:7, D4:8, D4:9, D4:10, D4:13, D4:14, D4:15, D5:0, D5:1, D5:2, D5:5, D5:9, D5:10, D5:11, D5:12, D5:13, D5:14, D5:15: D
LED_R0, LED_R1: 2.7K OHM 1/8W
Q1: 60V 1.2A
R0, R1, R2, R3, R4, R5, R6, R7, R8, R9: 180 OHM 1/8W
R10: 510 OHM 1/8W
SW0:0: ESC
SW0:2: F1
SW0:3: F2
SW0:4: F3
SW0:5: F4
SW0:6: F5
SW0:7: F6
SW0:8: F7
SW0:9: F8
SW0:10: F9
SW0:11: F10
SW0:12: F11
SW0:13: F12
SW0:14: PRINT
SW0:15: SCROLL LOCK
SW1:0: `
SW1:1: 1
SW1:2: 2
SW1:3: 3
SW1:4: 4
SW1:5: 5
SW1:6: 6
SW1:7: 7
SW1:8: 8
SW1:9: 9
SW1:10: 0
SW1:11: -
SW1:12: =
SW1:13: BACK SPACE
SW1:14: INSERT
SW1:15: HOME
SW2:0: TAB
SW2:1: Q
SW2:2: W
SW2:3: E
SW2:4: R
SW2:5: T
SW2:6: Y
SW2:7: U
SW2:8: I
SW2:9: O
SW2:10: P
SW2:11: [
SW2:12: ]
SW2:13: \\
SW2:14: DELETE
SW2:15: END
SW3:0: CAPS LOCK
SW3:1: A
SW3:2: S
SW3:3: D
SW3:4: F
SW3:5: G
SW3:6: H
SW3:7: J
SW3:8: K
SW3:9: L
SW3:10: ;
SW3:11: '
SW3:13: ENTER
SW3:14: PAGE UP
SW3:15: PAUSE
SW4:0: LEFT SHIFT
SW4:1: Z
SW4:2: X
SW4:3: C
SW4:4: V
SW4:5: B
SW4:6: N
SW4:7: M
SW4:8: ,
SW4:9: .
SW4:10: /
SW4:13: RIGHT SHIFT
SW4:14: PAGE DOWN
SW4:15: UP
SW5:0: LEFT CTRL
SW5:1: LEFT WINDOWS
SW5:2: LEFT ALT
SW5:5: SPACE
SW5:9: RIGHT ALT
SW5:10: RIGHT WINDOWS
SW5:11: MENU
SW5:12: RIGHT CTRL
SW5:13: RIGHT
SW5:14: LEFT
SW5:15: DOWN
U0: TEENSYPP2; MODULE
U1: USB-MINI-B_EXT
VREG1: MC34063ABN

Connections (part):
/COL 0: D0:0.1 (A), D1:0.1 (A), D2:0.1 (A), D3:0.1 (A), D4:0.1 (A), D5:0.1 (A), U0.45 (PB0)
/COL 1: D1:1.1 (A), D2:1.1 (A), D3:1.1 (A), D4:1.1 (A), D5:1.1 (A), U0.46 (PB1)
/COL 2: D0:2.1 (A), D1:2.1 (A), D2:2.1 (A), D3:2.1 (A), D4:2.1 (A), D5:2.1 (A), U0.47 (PB2)
/COL 3: D0:3.1 (A), D1:3.1 (A), D2:3.1 (A), D3:3.1 (A), D4:3.1 (A), U0.48 (PB3)
/COL 4: D0:4.1 (A), D1:4.1 (A), D2:4.1 (A), D3:4.1 (A), D4:4.1 (A), U0.49 (PB4)
/COL 5: D0:5.1 (A), D1:5.1 (A), D2:5.1 (A), D3:5.1 (A), D4:5.1 (A), D5:5.1 (A), U0.50 (PB5)
/COL 6: D0:6.1 (A), D1:6.1 (A), D2:6.1 (A), D3:6.1 (A), D4:6.1 (A), U0.51 (PB6)
/COL 7: D0:7.1 (A), D1:7.1 (A), D2:7.1 (A), D3:7.1 (A), D4:7.1 (A), U0.2 (PB7)
/COL 8: D0:8.1 (A), D1:8.1 (A), D2:8.1 (A), D3:8.1 (A), D4:8.1 (A), U0.40 (PF0)
/COL 9: D0:9.1 (A), D1:9.1 (A), D2:9.1 (A), D3:9.1 (A), D4:9.1 (A), D5:9.1 (A), U0.39 (PF1)
/COL 10: D0:10.1 (A), D1:10.1 (A), D2:10.1 (A), D3:10.1 (A), D4:10.1 (A), D5:10.1 (A), U0.38 (PF2)
/COL 11: D0:11.1 (A), D1:11.1 (A), D2:11.1 (A), D3:11.1 (A), D5:11.1 (A), U0.37 (PF3)
/COL 12: D0:12.1 (A), D1:12.1 (A), D2:12.1 (A), D5:12.1 (A), U0.36 (PF4)
/COL 13: D0:13.1 (A), D1:13.1 (A), D2:13.1 (A), D3:13.1 (A), D4:13.1 (A), D5:13.1 (A), U0.35 (PF5)
/COL 14: D0:14.1 (A), D1:14.1 (A), D2:14.1 (A), D3:14.1 (A), D4:14.1 (A), D5:14.1 (A), U0.34 (PF6)
/COL 15: D0:15.1 (A), D1:15.1 (A), D2:15.1 (A), D3:15.1 (A), D4:15.1 (A), D5:15.1 (A), U0.33 (PF7)
/GND: BC_Co1.2, BC_Ct1.2, BC_Cvcc1.2, BC_R1.2, D0.2 (K), D1.2 (K), Q1.2 (S), U0.1 (GND), VREG1.2 (Sw_Emit), VREG1.4 (GND)
/LED 0: LED_R0.2, U0.18 (PC5)
/LED 1: LED_R1.2, U0.19 (PC6)
/LEDCOL0: BC_Co1.1, BC_D1.2 (K), BC_R2.2, SW0:0.4, SW0:9.4, SW1:0.4, SW1:8.4, SW2:0.4, SW2:8.4, SW3:0.4, SW3:8.4, SW4:0.4, SW4:13.4, SW5:0.4
/LEDROW0: R0.2, SW0:8.3
/LEDROW1: R1.2, SW1:7.3
/LEDROW2: R2.2, SW2:7.3
/LEDROW3: R3.2, SW3:7.3
/LEDROW4: R4.2, SW4:7.3
/LEDROW5: R5.2, SW5:12.3
/LEDROW6: R6.2, SW1:15.3
/LEDROW7: R7.2, SW2:15.3
/LEDROW8: R8.2, SW3:15.3
/LEDROW9: R9.2, SW4:10.3
/LEDROW10: R10.2, SW3:14.3
/Q1: Q1.1 (G), U0.4 (PD1)
/ROW 0: SW0:0.1, SW0:2.1, SW0:3.1, SW0:4.1, SW0:5.1, SW0:6.1, SW0:7.1, SW0:8.1, SW0:9.1, SW0:10.1, SW0:11.1, SW0:12.1, SW0:13.1, SW0:14.1, SW0:15.1, U0.13 (PC0)
/ROW 1: SW1:0.1, SW1:1.1, SW1:2.1, SW1:3.1, SW1:4.1, SW1:5.1, SW1:6.1, SW1:7.1, SW1:8.1, SW1:9.1, SW1:10.1, SW1:11.1, SW1:12.1, SW1:13.1, SW1:14.1, SW1:15.1, U0.14 (PC1)
/ROW 2: SW2:0.1, SW2:1.1, SW2:2.1, SW2:3.1, SW2:4.1, SW2:5.1, SW2:6.1, SW2:7.1, SW2:8.1, SW2:9.1, SW2:10.1, SW2:11.1, SW2:12.1, SW2:13.1, SW2:14.1, SW2:15.1, U0.15 (PC2)
/ROW 3: SW3:0.1, SW3:1.1, SW3:2.1, SW3:3.1, SW3:4.1, SW3:5.1, SW3:6.1, SW3:7.1, SW3:8.1, SW3:9.1, SW3:10.1, SW3:11.1, SW3:13.1, SW3:14.1, SW3:15.1, U0.16 (PC3)
/ROW 4: SW4:0.1, SW4:1.1, SW4:2.1, SW4:3.1, SW4:4.1, SW4:5.1, SW4:6.1, SW4:7.1, SW4:8.1, SW4:9.1, SW4:10.1, SW4:13.1, SW4:14.1, SW4:15.1, U0.17 (PC4)
/ROW 5: SW5:0.1, SW5:1.1, SW5:2.1, SW5:5.1, SW5:9.1, SW5:10.1, SW5:11.1, SW5:12.1, SW5:13.1, SW5:14.1, SW5:15.1, U0.20 (PC7)
unnamed: D1:7.2 (K), SW1:7.2
unnamed: D2:7.2 (K), SW2:7.2
unnamed: D3:6.2 (K), SW3:6.2
unnamed: D4:6.2 (K), SW4:6.2
unnamed: D2:6.2 (K), SW2:6.2
unnamed: D3:5.2 (K), SW3:5.2
unnamed: D0:8.2 (K), SW0:8.2
unnamed: D4:5.2 (K), SW4:5.2
unnamed: D0:7.2 (K), SW0:7.2
unnamed: D0:9.2 (K), SW0:9.2
unnamed: D1:9.2 (K), SW1:9.2
unnamed: D4:7.2 (K), SW4:7.2
unnamed: D2:9.2 (K), SW2:9.2
unnamed: D3:8.2 (K), SW3:8.2
unnamed: D2:8.2 (K), SW2:8.2
unnamed: D1:8.2 (K), SW1:8.2
unnamed: D3:7.2 (K), SW3:7.2
unnamed: D5:2.2 (K), SW5:2.2
unnamed: D0:4.2 (K), SW0:4.2
unnamed: D1:4.2 (K), SW1:4.2
unnamed: D2:4.2 (K), SW2:4.2
unnamed: D1:3.2 (K), SW1:3.2
unnamed: D2:3.2 (K), SW2:3.2
unnamed: D3:3.2 (K), SW3:3.2
unnamed: D3:2.2 (K), SW3:2.2
unnamed: D4:2.2 (K), SW4:2.2
unnamed: D3:4.2 (K), SW3:4.2
unnamed: D4:4.2 (K), SW4:4.2
unnamed: D2:5.2 (K), SW2:5.2
unnamed: D0:6.2 (K), SW0:6.2
unnamed: D1:6.2 (K), SW1:6.2
unnamed: D0:5.2 (K), SW0:5.2
unnamed: D4:3.2 (K), SW4:3.2
unnamed: D1:5.2 (K), SW1:5.2
unnamed: D3:13.2 (K), SW3:13.2
unnamed: D4:13.2 (K), SW4:13.2
unnamed: D5:12.2 (K), SW5:12.2
unnamed: D0:14.2 (K), SW0:14.2
unnamed: D1:14.2 (K), SW1:14.2
unnamed: D2:14.2 (K), SW2:14.2
unnamed: D5:14.2 (K), SW5:14.2
unnamed: D3:11.2 (K), SW3:11.2
unnamed: D5:11.2 (K), SW5:11.2
unnamed: D0:13.2 (K), SW0:13.2
unnamed: D1:13.2 (K), SW1:13.2
unnamed: D2:13.2 (K), SW2:13.2
unnamed: D4:14.2 (K), SW4:14.2
unnamed: D3:15.2 (K), SW3:15.2
unnamed: D3:14.2 (K), SW3:14.2
unnamed: D5:15.2 (K), SW5:15.2
unnamed: D5:13.2 (K), SW5:13.2
unnamed: D2:0.2 (K), SW2:0.2
unnamed: D0:15.2 (K), SW0:15.2
unnamed: D1:15.2 (K), SW1:15.2
unnamed: D2:15.2 (K), SW2:15.2
unnamed: D4:15.2 (K), SW4:15.2
unnamed: D4:9.2 (K), SW4:9.2
unnamed: D2:10.2 (K), SW2:10.2
unnamed: D3:9.2 (K), SW3:9.2
unnamed: D5:9.2 (K), SW5:9.2
unnamed: D0:11.2 (K), SW0:11.2
unnamed: D0:10.2 (K), SW0:10.2
unnamed: D4:8.2 (K), SW4:8.2
unnamed: D5:5.2 (K), SW5:5.2
unnamed: D1:10.2 (K), SW1:10.2
unnamed: D1:12.2 (K), SW1:12.2
unnamed: D5:10.2 (K), SW5:10.2
unnamed: D0:12.2 (K), SW0:12.2
unnamed: D2:12.2 (K), SW2:12.2
unnamed: D1:11.2 (K), SW1:11.2
unnamed: D2:11.2 (K), SW2:11.2
unnamed: D3:10.2 (K), SW3:10.2
unnamed: D4:10.2 (K), SW4:10.2
unnamed: CON1.5 (GND), U1.5
unnamed: CON1.4 (ID), U1.4
unnamed: CON1.3 (D+), U1.3
unnamed: CON1.2 (D-), U1.2
unnamed: CON1.1 (VBUS), U1.1
unnamed: SW3:14.4, SW4:14.3
unnamed: SW4:14.4, SW4:15.3
unnamed: D0.1 (A), LED_R0.1
unnamed: SW4:15.4, SW5:13.3
unnamed: SW5:13.4, SW5:15.3
unnamed: D1.1 (A), LED_R1.1
unnamed: BC_R1.1, BC_R2.1, VREG1.5 (V_Sense)
unnamed: BC_D1.1 (A), BC_L1.2, VREG1.1 (Sw_Coll)
unnamed: BC_Cvcc1.1, BC_F1.1, BC_Rsc1.1, VREG1.6 (VCC)
unnamed: BC_F1.2, U0.52 (VCC)
unnamed: BC_R0.2, VREG1.8 (Drv_Coll)
unnamed: BC_Ct1.1, VREG1.3 (Tim_Cap)
unnamed: SW2:14.3, SW2:15.4
unnamed: SW4:13.3, SW5:14.4
unnamed: SW3:11.3, SW3:13.4
unnamed: SW3:13.3, SW4:8.4
unnamed: SW2:2.3, SW2:3.4
unnamed: BC_L1.1, BC_R0.1, BC_Rsc1.2, VREG1.7 (I_Sense)
unnamed: D0:0.2 (K), SW0:0.2
unnamed: D1:1.2 (K), SW1:1.2
unnamed: SW5:9.3, SW5:10.4
unnamed: D2:1.2 (K), SW2:1.2
unnamed: D3:0.2 (K), SW3:0.2
unnamed: SW1:9.3, SW1:10.4
unnamed: SW2:12.3, SW2:13.4
unnamed: SW2:11.3, SW2:12.4
unnamed: SW2:10.3, SW2:11.4
unnamed: SW2:9.3, SW2:10.4
unnamed: SW2:8.3, SW2:9.4
unnamed: SW1:14.3, SW1:15.4
unnamed: SW1:13.3, SW1:14.4
unnamed: SW1:12.3, SW1:13.4
unnamed: SW1:11.3, SW1:12.4
unnamed: SW1:10.3, SW1:11.4
unnamed: SW1:8.3, SW1:9.4
unnamed: SW0:14.3, SW0:15.4
unnamed: SW0:13.3, SW0:14.4
unnamed: SW0:12.3, SW0:13.4
unnamed: SW0:11.3, SW0:12.4
unnamed: SW0:10.3, SW0:11.4
unnamed: SW0:9.3, SW0:10.4
unnamed: SW5:11.3, SW5:12.4
unnamed: SW5:10.3, SW5:11.4
unnamed: D3:1.2 (K), SW3:1.2
unnamed: D4:1.2 (K), SW4:1.2
unnamed: D5:1.2 (K), SW5:1.2
unnamed: D0:3.2 (K), SW0:3.2
unnamed: D0:2.2 (K), SW0:2.2
unnamed: D4:0.2 (K), SW4:0.2
unnamed: D5:0.2 (K), SW5:0.2
unnamed: SW2:13.3, SW2:14.4
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

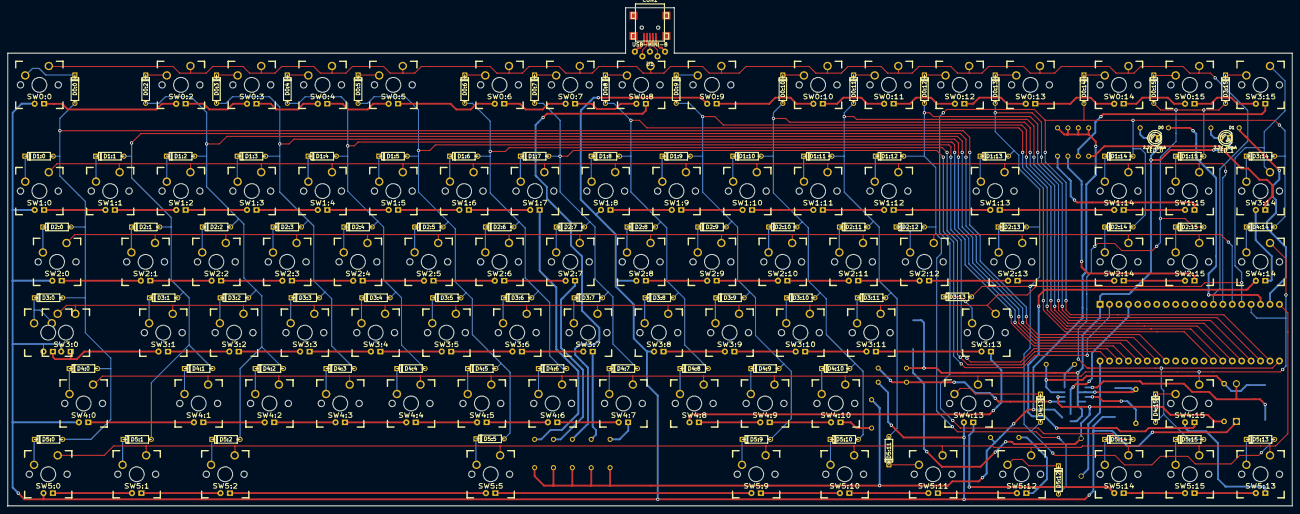
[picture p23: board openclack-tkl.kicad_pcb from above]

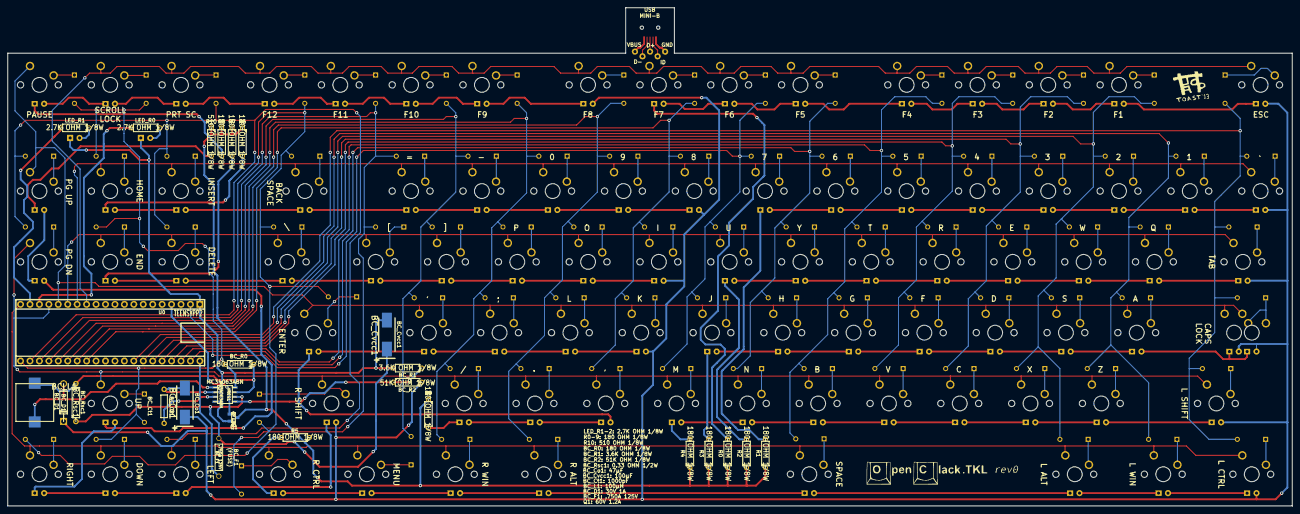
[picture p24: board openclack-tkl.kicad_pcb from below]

Board: 2 copper layers, 345.7 x 134.1 mm, 204 parts (26 on the bottom side), 216 nets.

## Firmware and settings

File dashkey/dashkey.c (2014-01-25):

/*
             LUFA Library
     Copyright (C) Dean Camera, 2010.

  dean [at] fourwalledcubicle [dot] com
           www.lufa-lib.org
*/

/*
  Copyright 2010  Dean Camera (dean [at] fourwalledcubicle [dot] com)

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
  The author disclaim all warranties with regard to this
  software, including all implied warranties of merchantability
  and fitness.  In no event shall the author be liable for any
  special, indirect or consequential damages or any damages
  whatsoever resulting from loss of use, data or profits, whether
  in an action of contract, negligence or other tortious action,
  arising out of or in connection with the use or performance of
  this software.
*/

/** \file
 *
 *  Main source file for the dashkey open-source keyboard controller
 *  The code is responsible for key detection, USB interfacing, macro support and (optionally) LED output
 */

#include "dashkey.h"

//eeprom_write_block((const void*)&x, (void*)&eeWayPts, 1);
//eeprom_read_block((void*)&y, (const void*)&eeWayPts, 1);
//pgm_read_byte(&(keycodes[i][j]))

#ifdef LED_MATRIX_SUPPORT
	uint8_t ledshift = 0; //#power transistor and PWM selection variable
	uint8_t ledmodeset = 0; //#The currently set LED mode. Can be overriden by Fn
	uint8_t	ledanimationkey = 0; //#Used for tracking iterations in LED animations
	bool 	ledanimationtoggle = 0; //#Used for tracking  state flips or ticks in LED animations
	uint8_t keytrails[12][2] = {{0, 0}, {0, 0}, {0, 0}, {0, 0}, {0, 0}, {0, 0}}; //tracks pressed keys and their timeouts for keytrails
	uint8_t ledmatrix[8][16]; //#stores matrix of active LEDs. One LED is stored per byte, with the upper 4 bits being D/C and the lowest bit being an on/off state.
							  //Upper 3 bits of the lower nibble are brightness value (0-7)
							  //0-7 is MSB, 8-15 is LSB (MSB is sent first). 5-7 are null.

	uint8_t frame_update = 0; //#counter tracking timing for animation updates. 5ms base timer.
#endif

uint8_t testcount = 0; //Test count to flash the teensy's built-in LED

uint8_t keyshift = 0; //#shift variable for keymatrix
uint8_t keymatrixA[16]; //#stores matrix of detected keys

uint8_t reportcodes[6] = {0}; //#stores set of current keys to report
uint8_t newcodes[6] = {0}; //stores just-acquired set of keys for debouncing/input
uint8_t oldcodes[6] = {0}; //stores set of previously acquired (5ms or 10ms ago) keys for debouncing
uint8_t reportmodifiers = 0; //#stores set of current modifiers to report
uint8_t newmodifiers = 0; //stores set of just-acquired modifiers  for debouncing/input
uint8_t oldmodifiers = 0; //stores set of previously acquired  (5ms ago) modifiers  for debouncing

//Macro variables
uint8_t macromatrix[16]; //Stores a bit matrix of keys currently set to use a macro key instead of their default behaviour.
						 //Used for doing a quick check if we should iterate through the macro list or not to find an active key
uint8_t macrolist[18];      //Stores the array of active macro key to keycode mappings. Currently long enough to have 18 macros, will need to extend
                  	  	 //if we want to support MR, M1-3 and LCD keys as well
uint8_t reportmacros[3]; //bitstuffed array containing current macros to report. Space for 24 keys, currently using 18
uint8_t newmacros[3];	 //bitstuffed array containing just-acquired macro keys
uint8_t oldmacros[3];	//bitstuffed array containing previously acquired macros for debouncing
uint8_t macro_waitforkey; //Used for timing the addition of macro keys to the array when setting

//TODO: We should migrate this into eeprom so that it can be reprogrammed
#ifdef OPENCLACK
//openclack keymatrix
uint8_t keycodes[16][8] PROGMEM = {{0x29, 0x00, 0x3A, 0x3B, 0x3C, 0x3D, 0x3E, 0x3F},	//pb row 0, keycode matrix; edit this to change keymap. Fn slotted in as 0xFF
							       {0x40, 0x41, 0x42, 0x43, 0x44, 0x45, 0x46, 0x47},	//pf row 0
							       {0x35, 0x1E, 0x1F, 0x20, 0x21, 0x22, 0x23, 0x24},	//pb row 1
							       {0x25, 0x26, 0x27, 0x2D, 0x2E, 0x2A, 0x49, 0x4A},	//pf row 1
							       {0x2B, 0x14, 0x1A, 0x08, 0x15, 0x17, 0x1C, 0x18},	//pb row 2
							       {0x0C, 0x12, 0x13, 0x2F, 0x30, 0x31, 0x4C, 0x4D},	//pf row 2
							       {0x39, 0x04, 0x16, 0x07, 0x09, 0x0A, 0x0B, 0x0D},	//pb row 3
							       {0x0E, 0x0F, 0x33, 0x34, 0x00, 0x28, 0x4B, 0x48},	//pf row 3
							       {0xE1, 0x1D, 0x1B, 0x06, 0x19, 0x05, 0x11, 0x10},	//pb row 4
							       {0x36, 0x37, 0x38, 0x00, 0x00, 0xE5, 0x4E, 0x52},	//pf row 4
							       {0xE0, 0xE3, 0xE2, 0x00, 0x00, 0x2C, 0x00, 0x00},	//pb row 5
							       {0x00, 0xE6, 0xE7, 0x65, 0xE4, 0x4F, 0x50, 0x51}};	//pf row 5
#else
//dashkey-custom keymatrix
uint8_t keycodes[16][8] PROGMEM = {{0x2E, 0x25, 0x36, 0x03, 0x0E, 0x3F, 0x0C, 0x30}, //keycode matrix; edit this to change keymap. Fn slotted in as 0xFF
							       {0x41, 0x26, 0x37, 0x65, 0x0F, 0x03, 0x12, 0x40},
							       {0x22, 0x21, 0x19, 0x05, 0x09, 0x0A, 0x15, 0x17},
							       {0x23, 0x24, 0x10, 0x11, 0x0D, 0x0B, 0x18, 0x1C},
							       {0x35, 0x1E, 0x1D, 0x03, 0x04, 0x29, 0x14, 0x2B},
							       {0xE0, 0x3E, 0xE4, 0x03, 0x04, 0x03, 0x48, 0x06},
							       {0x3B, 0x20, 0x06, 0x03, 0x07, 0x3D, 0x08, 0x3C},
							       {0x3A, 0x1F, 0x1B, 0x03, 0x16, 0x03, 0x1A, 0x39},
							       {0x4A, 0x4D, 0x03, 0x50, 0x58, 0x52, 0x57, 0x07},
							       {0x03, 0x03, 0x03, 0x03, 0xE5, 0x03, 0x03, 0xE1},
							       {0x49, 0x03, 0x54, 0x4F, 0x5A, 0x62, 0x60, 0x5D},
							       {0x4B, 0x4E, 0x55, 0x56, 0x5B, 0x63, 0x61, 0x5E},
							       {0x42, 0x43, 0x28, 0x45, 0x31, 0x44, 0x1A, 0x2A},
							       {0x4C, 0x03, 0x53, 0x51, 0x59, 0x2C, 0x5F, 0x5C},
							       {0x2D, 0x27, 0x03, 0x38, 0x33, 0x34, 0x13, 0x2F},
							       {0x03, 0x46, 0x03, 0xE6, 0xFF, 0xE2, 0x47, 0xE3}};
#endif

#ifdef LED_MATRIX_SUPPORT
//TODO: We should migrate this into eeprom so that it can be reprogrammed
uint8_t keytoled[7][16] PROGMEM = {{0x07, 0x07, 0x07, 0x07, 0x1B, 0x5C, 0x3C, 0x3B, 0x3A, 0x4B, 0x5B, 0x6B, 0x00, 0x7B, 0x01, 0x11}, //key to LED translation table
								   {0x7C, 0x6C, 0x10, 0x20, 0x1A, 0x4A, 0x2B, 0x5A, 0x7A, 0x4C, 0x2A, 0x2C, 0x6A, 0x1C, 0x19, 0x29},
								   {0x39, 0x49, 0x59, 0x69, 0x79, 0x0F, 0x1F, 0x2F, 0x41, 0x08, 0x5F, 0x0A, 0x3D, 0x3F, 0x4F, 0x30},
								   {0x40, 0x50, 0x07, 0x21, 0x31, 0x09, 0x02, 0x12, 0x22, 0x0B, 0x18, 0x28, 0x38, 0x48, 0x58, 0x68},
								   {0x78, 0x0E, 0x1E, 0x2E, 0x3E, 0x4E, 0x5E, 0x6E, 0x7E, 0x6F, 0x7F, 0x04, 0x60, 0x70, 0x44, 0x23},
								   {0x03, 0x13, 0x42, 0x14, 0x24, 0x34, 0x73, 0x63, 0x53, 0x52, 0x62, 0x72, 0x51, 0x61, 0x71, 0x54},
								   {0x64, 0x74, 0x33, 0x43, 0x07, 0x6D, 0x07, 0x07, 0x0D, 0x0C, 0x2D, 0x1D, 0x7D, 0x32, 0x4D, 0x5D}};
#endif

//G-key matrix; translates a G-key number (G1-G18) into its byte/bit value. Stored with the bit value in 4 LSB and byte value in 4 MSB
//The rest of the array stores, in order, MR, M1-M3, LCD0-LCD4
uint8_t gcodes[27] PROGMEM = { 0x00, 0x11, 0x22, 0x33, 0x44, 0x55, 0x10, 0x21, 0x32,
							   0x43, 0x54, 0x65, 0x02, 0x13, 0x24, 0x35, 0x46, 0x76,
							   0x62, 0x50, 0x61, 0x72, 0x77, 0x17, 0x27, 0x37, 0x47};

uint8_t funcmode = 0; //#Set to 1 when the Function key is held down, 2 when in macro programming mode
uint8_t update_keys = 0; //#keymatrix updater count; used to time 5ms increments to refill keymatrix
uint8_t update_keys_max = 2; //Maximum value for update_keys checking; used for debounce tweaking
uint8_t brightness = 255; //Current value for global brightness
uint8_t brightness_count = 0; //Current value for global brightness thresh-hold for LED rates
bool brightness_wait = false; //Variable to tell when brightness value has been pushed out
#define BRIGHTNESS_STEPSIZE 15

AppPtr_t BootStartPtr = (AppPtr_t)0x7000;

/** Buffer to hold the previously generated Keyboard HID report, for comparison purposes inside the HID class driver. */
static uint8_t PrevKeyboardHIDReportBuffer[sizeof(USB_KeyboardReport_Data_t)];

/** Buffer to hold the previously generated Keyboard HID report, for comparison purposes inside the HID class driver. */
static uint8_t PrevMacroHIDReportBuffer[sizeof(USB_MacroReport_Data_t)];

/** Buffer to hold the previously generated Keyboard HID report, for comparison purposes inside the HID class driver. */
static uint8_t PrevMediaHIDReportBuffer[sizeof(USB_MediaReport_Data_t)];


/** LUFA HID Class driver interface configuration and state information. This structure is
 *  passed to all HID Class driver functions, so that multiple instances of the same class
 *  within a device can be differentiated from one another.
 */
USB_ClassInfo_HID_Device_t Keyboard_HID_Interface =
 	{
		.Config =
			{
				.InterfaceNumber              = 0,

				{
					.Address              = KEYBOARD_EPADDR,
					.Size                 = HID_EPSIZE,
					.Banks                = 1,
				},

				.PrevReportINBuffer           = PrevKeyboardHIDReportBuffer,
				.PrevReportINBufferSize       = sizeof(PrevKeyboardHIDReportBuffer),
			},
    };

/** LUFA HID Class driver interface configuration and state information. This structure is
 *  passed to all HID Class driver functions, so that multiple instances of the same class
 *  within a device can be differentiated from one another.
 */
USB_ClassInfo_HID_Device_t Macro_HID_Interface =
 	{
		.Config =
			{
				.InterfaceNumber              = 0,

				{
					.Address              = MACRO_EPADDR,
					.Size                 = HID_EPSIZE,
					.Banks                = 1,
				},

				.PrevReportINBuffer           = PrevMacroHIDReportBuffer,
				.PrevReportINBufferSize       = sizeof(PrevMacroHIDReportBuffer),
			},
    };

/** LUFA HID Class driver interface configuration and state information. This structure is
 *  passed to all HID Class driver functions, so that multiple instances of the same class
 *  within a device can be differentiated from one another.
 */
USB_ClassInfo_HID_Device_t Media_HID_Interface =
 	{
		.Config =
			{
				.InterfaceNumber              = 0,

				{
					.Address              = MEDIA_EPADDR,
					.Size                 = HID_EPSIZE,
					.Banks                = 1,
				},

				.PrevReportINBuffer           = PrevMediaHIDReportBuffer,
				.PrevReportINBufferSize       = sizeof(PrevMediaHIDReportBuffer),
			},
    };

/** Main program entry point. This routine contains the overall program flow, including initial
 *  setup of all components and the main program loop.
 */
#ifdef OPENCLACK //If we're using openclack, we read two bytes at a time
	static inline uint8_t readmatrixrow(void) {
		//TODO: Input a return for the first byte read
		return ~PINB;
	}
	static inline uint8_t readmatrixrow2(void) {
		return ~PINF;
	}
#else //Dashkey-custom reads a single byte and iterates more rows instead
	static inline uint8_t readmatrixrow(void) {
		return ~((PIND&0b01111111)<<1 | ((PINC>>2)&0b00000001)); //amalgamate PC2 and PD0-6 into an 8-bit int containing a single keymatrix row
	}
#endif

#ifndef OPENCLACK	//We only need SPI functionality if we're using dashkey-custom
static inline void LATCH_KEY(void) {PORTB |= 0x01; PORTB &= 0xFE;} //flips !SS (PB0) high then low to latch keymatrix driver
static inline void LATCH_LED(void) {PORTB |= (1<<PB5); PORTB &= ~(1<<PB5);} //flips PB5 high then low to latch LED drivers

/*
static inline void SPI8_Send(uint8_t cData) //Sends a single SPI byte. Typically unused, kept for compatibility
{
	SPDR = cData; //Start transmission
	while(!(SPSR & (1<<SPIF))); //Wait for the transmission to complete
}
*/

static inline void SPI16_Send(uint8_t bighalf,uint8_t smallhalf) //Sends two SPI bytes
{
	SPDR = bighalf; //Start transmission
	while(!(SPSR & (1<<SPIF))); //Wait for the transmission to complete
	SPDR = smallhalf; //Start transmission
	while(!(SPSR & (1<<SPIF))); //Wait for the transmission to complete
}

//These two static inlines are used to disable and enable TIMER0's interrupt briefly to prevent TIMER0 from pushing out an SPI update during led_driver updates which can cause flickering
static inline void et0i(void) {TIMSK0 |= (1 << 1);} // Enable TIMER0's CTC interrupt
static inline void dt0i(void) {TIMSK0 &= ~(1 << 1);} // Disable TIMER0's CTC interrupt
#endif


int main(void)
{
	SetupHardware();
	sei();

	for (;;)
	{
		HID_Device_USBTask(&Keyboard_HID_Interface);
		HID_Device_USBTask(&Macro_HID_Interface);
		HID_Device_USBTask(&Media_HID_Interface);
		USB_USBTask();
		process_keys();
#ifdef LED_MATRIX_SUPPORT
		led_driver();
#endif
	}
}

/** Configures the board hardware and chip peripherals for the demo's functionality. */
//TODO: Break this functionality out to allow support for different board layouts, like the LED and button files. We can hook the MCU type definition to decide what to use.
void SetupHardware()
{
	/* Disable watchdog if enabled by bootloader/fuses */
	MCUSR &= ~(1<<WDRF);
	wdt_disable();

	/* Disable clock division */
    CLKPR=0x80; //set the prescaler change enable bit high
	CLKPR=0x00; //remove the /8 clock prescaler division and set change enable low

	/* Hardware Initialization */
#ifndef OPENCLACK
	DDRB |= (1<<DDB5)|(1<<DDB4); //set LED driver latch and dataflash !CS as output
	PORTB |= (1<<PB4); //Set dataflash !CS pin high at startup (chip disabled)
	PORTB &= ~(1<<PB5); //Set LED driver latch low at startup
	SPI_MasterInit();
#else
	DDRD |= (1<<DDD6); //Enable the PD6 LED pin
//	PORTD |= (1<<PD6); //Set the pin to one
	PORTD &= ~(1<<PD6); //Set the pin to zero
	DDRC |= 0b10011111; //Set the row pins as outputs
	DDRD |= (1<<DDD1); //Enable the key LED PWM mosfet's pin as output
//	PORTD |= (1<<PD1); //Set the pin to one
	PORTD &= ~(1<<PD1); //Set the pin to zero
#endif
	LEDs_Init();
	KeyMatrix_Init();
	USB_Init();
	Timer_Init();

}

void Timer_Init(void){
	   TCCR0A |= (1 << 1); // Configure timer 0 for CTC mode (would use WGM01, but it's pointing to 3 for some reason...)
	   TIMSK0 |= (1 << 1); // Enable TIMER0's CTC interrupt
	   OCR0A   = 16; // Set CTC compare value to 16 (64uS at 16MHz AVR clock), with a prescaler of 64
	   TCCR0B |= ((1 << CS00) | (1 << CS01)); // Start timer at Fcpu/64, giving us a resolution of 4uS

	   TCCR1B |= (1 << WGM12) | (1 << CS11) | (1 << CS10); //set the 16-bit timer to CTC mode and use fclk/64 prescaler
	   OCR1AH = 0x04; //set the compare value to 1250, resulting in a 5ms (200Hz)  trigger, suitable for animation timing and debouncing
	   OCR1AL = 0xE2;
	   TIMSK1 |= (1<<1); //Enable TIMER1's CTC interrupt
}

#ifdef LED_MATRIX_SUPPORT
	void led_driver(void){ //LED control function, responsible for populating ledmatrix[][] with the right values to get sent out on timed interrupt
						   //In cases where it matters (when we clear then set, or set then clear LEDs in a single operation) we disable then re-enable the timer to prevent flickering
		switch((ledmodeset&(0xFF*!(bool)funcmode)) | ((funcmode)<<6)) //Selects an LED display pattern. Bitstuff the funcmode value into ledmodeset to detect Fn cases
		{
			case 0: //All LEDs off case
				if(frame_update >= 20) {
					ledanim_clear();
					frame_update = 0;
				}
				break;
			case 1: //All LEDs off case with lit status LEDs
				if(frame_update >= 20) {
					dt0i(); //Disables TIMER0's interrupt to prevent flickering
					ledanim_clear();
					if(LEDs_GetLEDs()&0x80) ledanim_lightkey(0x53, 0x07); //Num Lock
					if(LEDs_GetLEDs()&0x40) ledanim_lightkey(0x39, 0x07); //Caps Lock
					if(LEDs_GetLEDs()&0x20) ledanim_lightkey(0x47, 0x07); //Scroll Lock
					et0i(); //Enables TIMER0's interrupt again
					frame_update = 0;
				}
				break;
			case 2: //All LEDs on case
				if(frame_update >= 20) {
					ledanim_full(0x07);
					frame_update = 0;
				}
				break;
			case 3: //All LEDs on case with unlit status LEDs
				if(frame_update >= 20) {
					dt0i();
					ledanim_full(0x07);
					if(LEDs_GetLEDs()&0x80) ledanim_clearkey(0x53); //Num Lock
					if(LEDs_GetLEDs()&0x40) ledanim_clearkey(0x39); //Caps Lock
					if(LEDs_GetLEDs()&0x20) ledanim_clearkey(0x47); //Scroll Lock
					et0i();
					frame_update = 0;
				}
				break;
			case 4: //All LEDs on at minimum brightness
				if(frame_update >= 20) {
					ledanim_full(0x00);
					frame_update = 0;
				}
				break;
	/*		case 5: //Thatch pattern case
				if(frame_update >= 40) {
					dt0i();
					ledanim_full(0x07);
					ledanim_clearrow(1);
					ledanim_clearrow(3);
					ledanim_clearrow(5);
					ledanim_clearrow(7);
					//TODO: We don't have flipcolumn and fliprow functions yet
		//			ledanim_flipcolumn(0);
		//			ledanim_flipcolumn(2);
		//			ledanim_flipcolumn(4);
		//			ledanim_flipcolumn(9);
		//			ledanim_flipcolumn(11);
		//			ledanim_flipcolumn(13);
		//			ledanim_flipcolumn(15);
					et0i();
					frame_update = 0;
				}
				break;
	*/		case 6: //Alphabet soup
				if(frame_update >= 10) {
					dt0i();
					ledanim_clear();
					ledanim_lightkey(ledanimationkey+0x04,0x07);
					et0i();
					if(ledanimationkey>=0x19) ledanimationkey = 0x00;
					else ledanimationkey++;
					frame_update = 0;
				}
				break;
			case 7: //Fade test
				if(frame_update >= 20) {
					ledanim_full(ledanimationkey);
					if (ledanimationkey >= 7) ledanimationtoggle = 1;
					if (ledanimationkey == 0) ledanimationtoggle = 0;
					if(ledanimationtoggle) ledanimationkey--;
					else ledanimationkey++;
					frame_update = 0;
				}
				break;
			case 8: //SX Fading Logo  Test
				if(frame_update >= 40) {
					ledanim_clear();
					ledanim_lightkey(0x21,ledanimationkey);
					ledanim_lightkey(0x22,ledanimationkey);
					ledanim_lightkey(0x08,ledanimationkey);
					ledanim_lightkey(0x09,ledanimationkey);
					ledanim_lightkey(0x06,ledanimationkey);
					ledanim_lightkey(0x1B,ledanimationkey);
					ledanim_lightkey(0x24,ledanimationkey);
					ledanim_lightkey(0x26,ledanimationkey);
					ledanim_lightkey(0x18,ledanimationkey);
					ledanim_lightkey(0x0C,ledanimationkey);
					ledanim_lightkey(0x0D,ledanimationkey);
					ledanim_lightkey(0x0E,ledanimationkey);
					ledanim_lightkey(0x11,ledanimationkey);
					ledanim_lightkey(0x36,ledanimationkey);
					if (ledanimationkey >= 7) ledanimationtoggle = 1;
					if (ledanimationkey == 0) ledanimationtoggle = 0;
					if(ledanimationtoggle) ledanimationkey--;
					else ledanimationkey++;
					frame_update = 0;
				}
				break;
			case 9: //Key Trails
				if(frame_update >= 10) {
					ledanim_clear();
					uint8_t matrixrow;
					uint8_t matrixcol;
					for(matrixrow = 0;matrixrow <=5;matrixrow++) {
						if(reportcodes[matrixrow] == 0) break; //break at end of report
						for(matrixcol = 0; matrixcol <=11; matrixcol++) {
							if (reportcodes[matrixrow] == keytrails[matrixcol][0]) {
								keytrails[matrixcol][1] = 10;
								break;
							}

						}
						if(matrixcol == 12) {
							for(matrixcol = 0; matrixcol <=11; matrixcol++) {
								if (keytrails[matrixcol][1] == 0) {
									keytrails[matrixcol][0] = reportcodes[matrixrow];
									keytrails[matrixcol][1] = 10;
									break;
								}

							}
						}
					}

					for(matrixcol = 0; matrixcol <=11; matrixcol++) {
						if(keytrails[matrixcol][1] != 0) {
							if(keytrails[matrixcol][1] > 0x07) ledanim_lightkey(keytrails[matrixcol][0], 0x07);
							else ledanim_lightkey(keytrails[matrixcol][0], keytrails[matrixcol][1]);
							keytrails[matrixcol][1]--;
						}
					}
	//				if (ledanimationkey >= 7) ledanimationtoggle = 1;
	//				if (ledanimationkey == 0) ledanimationtoggle = 0;
	//				if(ledanimationtoggle) ledanimationkey--;
	//				else ledanimationkey++;
					frame_update = 0;
				}
				break;
			case 64: //Fn on indicator case
				if(frame_update >= 20) {
					dt0i();
					ledanim_clear();
					ledanim_lightkey(ledmodeset+0x1E, 0x07); //keys 1 through 0, based on mode
					if(update_keys_max == 1) ledanim_lightkey(0x4B,0x07); //If using fast debouncing (5ms), light PgUP
					else ledanim_lightkey(0x4E,0x07); //If using slow debouncing (10ms), light PgDn
	//				if(CLKSEL1&0x80) ledanim_lightkey(0x3E, 0x07); //Used for diagnostic output
	//				if(CLKSEL1&0x40) ledanim_lightkey(0x3F, 0x07);
	//				if(CLKSEL1&0x20) ledanim_lightkey(0x40, 0x07);
	//				if(CLKSEL1&0x10) ledanim_lightkey(0x41, 0x07);
	//				if(CLKSEL1&0x08) ledanim_lightkey(0x42, 0x07);
	//				if(CLKSEL1&0x04) ledanim_lightkey(0x43, 0x07);
	//				if(CLKSEL1&0x04) ledanim_lightkey(0x43, 0x07);
	//				if(CLKSEL0&0x01) ledanim_lightkey(0x45, 0x07);
					et0i();
					frame_update= 0;
				}
				break;
			case 5:
			case 128: //Fn on macro setting case
				if(frame_update >= 20) {
					dt0i();
					ledanim_clear();
					//Light keys set as macro keys
					for(ledanimationkey = 0;ledanimationkey < 18;ledanimationkey++) {
						if(macrolist[ledanimationkey] != 0) {
							ledanim_lightkey(macrolist[ledanimationkey],0x07);
						}
					}
					et0i();
					frame_update = 0;
				}
				break;
			default:
				break;
		}
	}

	void ledanim_clear(void) { //Clears the entire LED matrix table (sets brightness values to full, but in off state)
		uint8_t ledmatrixcolumn;
		uint8_t ledmatrixrow;
		for(ledmatrixrow = 0;ledmatrixrow<8;ledmatrixrow++) {
			for(ledmatrixcolumn = 0; ledmatrixcolumn <5; ledmatrixcolumn++) {
				ledmatrix[ledmatrixrow][ledmatrixcolumn] = 0x0E; //
			}
			for(ledmatrixcolumn = 8; ledmatrixcolumn <16; ledmatrixcolumn++) {
				ledmatrix[ledmatrixrow][ledmatrixcolumn] = 0x0E; //
			}
		}
	}

	void ledanim_full(uint8_t brightness) { //Fills the entire LED matrix table at a given brightness
		uint8_t ledmatrixcolumn;
		uint8_t ledmatrixrow;
		for(ledmatrixrow = 0;ledmatrixrow<8;ledmatrixrow++) {
			for(ledmatrixcolumn = 0; ledmatrixcolumn <5; ledmatrixcolumn++) {
				ledmatrix[ledmatrixrow][ledmatrixcolumn] = 0x01 | ((brightness&0x07)<<1); //
			}
			for(ledmatrixcolumn = 8; ledmatrixcolumn <16; ledmatrixcolumn++) {
				ledmatrix[ledmatrixrow][ledmatrixcolumn] = 0x01 | ((brightness&0x07)<<1); //
			}
		}
	}
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

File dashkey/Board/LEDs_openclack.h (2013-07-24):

/*
             LUFA Library
     Copyright (C) Dean Camera, 2010.

  dean [at] fourwalledcubicle [dot] com
           www.lufa-lib.org
*/

/*
  Copyright 2010  Dean Camera (dean [at] fourwalledcubicle [dot] com)

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
  The author disclaim all warranties with regard to this
  software, including all implied warranties of merchantability
  and fitness.  In no event shall the author be liable for any
  special, indirect or consequential damages or any damages
  whatsoever resulting from loss of use, data or profits, whether
  in an action of contract, negligence or other tortious action,
  arising out of or in connection with the use or performance of
  this software.
*/

/** \file
 *  \brief Board specific LED driver header for the Atmel USBKEY.
 *
 *  Board specific LED driver header for the Atmel USBKEY.
 *
 *  \note This file should not be included directly. It is automatically included as needed by the LEDs driver
 *        dispatch header located in LUFA/Drivers/Board/LEDs.h.
 */

/** \ingroup Group_LEDs
 *  @defgroup Group_LEDs_USER USER
 *
 *  Board specific LED driver header for the openclack+teensy.
 *
 *  \note This file should not be included directly. It is automatically included as needed by the LEDs driver
 *        dispatch header located in LUFA/Drivers/Board/LEDs.h.
 *
 *  @{
 */

#ifndef __LEDS_USER_H__
#define __LEDS_USER_H__

	/* Includes: */
		#include <avr/io.h>

		#include "LUFA/Common/Common.h"

	/* Enable C linkage for C++ Compilers: */
		#if defined(__cplusplus)
			extern "C" {
		#endif

	/* Preprocessor Checks: */
		#if !defined(__INCLUDE_FROM_LEDS_H)
			#error Do not include this file directly. Include LUFA/Drivers/Board/LEDS.h instead.
		#endif

	/* Public Interface - May be used in end-application: */
		/* Macros: */
			//For openclack, PC5 is capslock, PC6 is scrllock

			/** LED mask for the first LED on the board. (NUMLOCK) */
			#define LEDS_LED1        (0 << 0) //No numlock for openclack

			/** LED mask for the second LED on the board. (CAPSLOCK) */
			#define LEDS_LED2        (1 << 5)

			/** LED mask for the third LED on the board. (SCROLLLOCK)*/
			#define LEDS_LED3        (1 << 6)

			/** LED mask for the fourth LED on the board. */
//			#define LEDS_LED4        (1 << 6)

			/** LED mask for all the LEDs on the board. */
			#define LEDS_ALL_LEDS    (LEDS_LED1 | LEDS_LED2 | LEDS_LED3)
			#define LEDS_ALLC_LEDS    0b01100000

			/** LED mask for none of the board LEDs. */
			#define LEDS_NO_LEDS     0

		/* Inline Functions: */
		#if !defined(__DOXYGEN__)
			static inline void LEDs_Init(void)
			{
				DDRC  |=  LEDS_ALLC_LEDS;
				PORTC |= LEDS_ALLC_LEDS;
			}

			static inline void LEDs_TurnOnLEDs(const uint8_t LEDMask)
			{
				PORTC &= ~(LEDMask&LEDS_ALLC_LEDS);
			}

			static inline void LEDs_TurnOffLEDs(const uint8_t LEDMask)
			{
				PORTC |= (LEDMask&LEDS_ALLC_LEDS);
			}

			static inline void LEDs_SetAllLEDs(const uint8_t LEDMask)
			{
				PORTC = ((PORTC & ~LEDS_ALLC_LEDS) | (~LEDMask & LEDS_ALLC_LEDS));
			}

			static inline void LEDs_ChangeLEDs(const uint8_t LEDMask,
			                                   const uint8_t ActiveMask)
			{
				PORTC = ((PORTC & ~(LEDMask&LEDS_ALLC_LEDS)) | (ActiveMask&LEDS_ALLC_LEDS));
			}

			static inline void LEDs_ToggleLEDs(const uint8_t LEDMask)
			{
				PORTC ^= LEDMask&LEDS_ALLC_LEDS;
			}

			static inline uint8_t LEDs_GetLEDs(void) ATTR_WARN_UNUSED_RESULT;
			static inline uint8_t LEDs_GetLEDs(void)
			{
				return (~PORTC&LEDS_ALLC_LEDS);
			}
		#endif

	/* Disable C linkage for C++ Compilers: */
		#if defined(__cplusplus)
			}
		#endif

#endif

/** @} */

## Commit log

2013-06-15 Bulk update.
    [toasty-tkl-Eco1_User.dxf, toasty-tkl-Eco2_User.dxf, toasty-tkl-Edge_Cuts.dxf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]
2013-06-16 Finished Case and made a 3D mock up in sketchup.
    Case files are in the dxf_plots dir.
    [3D_mockup.skp, acrylic_0.dxf, acrylic_1.dxf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]
2013-06-16 Multiple Changes
    Removed some useless old files
    Added wider holes in acrylic_2 in case I don't want to use the acrylic
    foot
    [acrylic_2.dxf, toasty-tkl-Eco1_User.dxf, toasty-tkl-Eco2_User.dxf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]
2013-06-17 Added more information on LED notes including parts.
    [3D_mockup.skp, toasty-tkl.sch]
2013-06-18 Updated Plate, final changes done. Sending to fab.
    [3D_mockup.skp, plate.dxf, toasty-tkl.kicad_pcb]
2013-06-19 Lots of changes, see extended description.
    -Changed screw hole size in acrylic as well as brass insert size to 4-40
    which seems to be more standard.
    -Made inkscape plots to have the acrylic fabbed at ponoko. Sent off for
    fab! : )
    -Revised the steel plate which I've requested a quote for as well.
    [acrylic_0.dxf, acrylic_2.dxf, acrylic_3.dxf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]
2013-06-21 Added GPL and killed some bogus cache files.
    [toasty-tkl.kicad_pcb, toasty-tkl.sch]
2013-06-24 Updates to kicad files. Added DXF plot altered for water jet shop.
    [plate_modded_4_waterjet_cut.dxf, toasty-tkl.kicad_pcb, toasty-tkl.sch]
2013-06-24 Fixed up my footprints, added into kicad diag.
    [toasty-tkl.kicad_pcb, toasty-tkl.sch]
2013-06-25 Did some preliminary traces for boost converter circuit.
    [toasty-tkl.kicad_pcb]
2013-06-26 Fixed fet pins.
    [toasty-tkl.kicad_pcb, toasty-tkl.sch]
2013-06-26 Small trace adjustments on boost converter. Needs review, changes, thicker wires, cleanup, fixing of labels... : (
    [toasty-tkl.kicad_pcb]
2013-06-27 Thickened all 10 mil vcc and gnd traces to 20mm and reogranised.
    [toasty-tkl.kicad_pcb, toasty-tkl.sch]
2013-06-28 Swapped Two Capacitors I had swapped earlier by accident. Rewired them. Split parts list away from led notes.
    [toasty-tkl.kicad_pcb]
2013-07-01 Finished parts list, fixed LED notes. double checked all parts, flipped boost converter parts all to rear of PCB.
    [toasty-tkl.kicad_pcb, toasty-tkl.sch]
2013-07-02 Added and fixed silk screen tags, added usb connector to part list.
    [toasty-tkl.kicad_pcb]
2013-07-02 Slight tweaks to silk screen and part list.
    [toasty-tkl.kicad_pcb]
2013-07-11 Cleaned up schematic around boost converter
    Edited for clarity and corrected one layout error (inductor/schottky
    connection)
    [toasty-tkl.sch]
2013-07-12 Removed unnecesarry joints, added values for parts in schema. Fixed traces.
    [toasty-tkl.kicad_pcb, toasty-tkl.sch]
2013-07-12 Rewired PD6 pin on teensy, it wouldn't work as a column pin. LED is present on the line.
    [toasty-tkl.kicad_pcb, toasty-tkl.sch]
2013-07-13 Fixed some traces. Added more silk screen text.
    [toasty-tkl.kicad_pcb, toasty-tkl.sch]
2013-07-13 did a couple trace changes
    [toasty-tkl.kicad_pcb]
2013-07-13 Adjusted silk screens.
    [toasty-tkl.kicad_pcb]
2013-07-14 Adjusted module positions. Increased silk screen font size.
    [toasty-tkl.kicad_pcb]
2013-07-14 Removed unnecessary vias, cleaned up GND
    Removed 3 vias from the boost converter area
    Removed an extra branch from a ground line running through the Teensy's
    Pin 1
    [toasty-tkl.kicad_pcb]
2013-07-14 Cleaned up files, made notes folder, removed old notes. Modified a few traces. Added logo and sig.
    [toasty-tkl.kicad_pcb]
2013-07-15 Project rev 0 complete.
    Renamed some project files, did gerber plots to send to fab. Made some
    small chagnes to parts list.
    [openclack-tkl.kicad_pcb, openclack-tkl.sch]
2013-07-20 Added initial dashkey firmware code dump
    Note: This code is *very incomplete* in terms of compatibility and
    testing with the Teensy used in openclack; it requires a number of
    changes and improvements to support that controller (it currently
    targets an atmega32u2 based design with a custom layout) so use at your
    own peril (for the moment).
    Eventually this code will include easy driver support for multiple
    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
2013-07-20 (Dashkey) Resolved boot keyboard support problems
    Broke the media key report off in to a separate endpoint so that the
    keyboard descriptor follows boot standard. This still allows us to use
    the media keys but it means the keyboard works in BIOS and other
    environments that don't fully interpret the USB descriptors
    [Descriptors.h, dashkey.c]
2013-07-21 unhid layer
    [openclack-tkl.kicad_pcb]
2013-07-24 Added support for openclack pinout/layout
    The dashkey header file now includes an OPENCLACK define that selects
    between the openclack layout and the dashkey-custom layout this firmware
    is originally derived from. The code as-is has been tested to flash and
    run correctly on an openclack board (and it enumerates the USB devices
    correctly) but doesn't seem to be passing keypresses or LEDs. Needs
    further investigation.
    [LEDs_dashkey-custom.h, LEDs_openclack.h, dashkey.c]
2013-07-24 Fixed error for LED2 (scroll lock) gnd pin, found in prototype.
    [openclack-tkl.kicad_pcb]
2013-07-24 Multiple pad revisions after inspecting prototype.
    Extended pads for BD_D1, USB MINI-B.
    Increased hole and pad size for BC_Ct1 and BC_D1.
    The old sizes work fine but this will make it easier to solder, give
    some extra wiggle room.
    [openclack-tkl.kicad_pcb]
2013-07-25 Set row pins as outputs, fix duplicate ROW5
    Set the pin direction for PC0-PC4 and PC7 to output so the rows can pull
    down hard
    Added an OR-check to keep PC7 high when the rowcount is 7 (since it
    already went high on rowcount 5)
    [dashkey.c]
2013-07-25 Fixed error with boost converter wiring for BC_R1 found in prototype.
    On the prototype this is an easy fix, basically you can just rotate the
    resistor to the side and solder it to the same pin the trace goes to in
    the diagram now.
    [openclack-tkl.kicad_pcb, openclack-tkl.sch]
2013-07-25 Disabled LED flash test.
2013-07-26 Fixed openclack scroll LED problem, fix matrices
    There was a missing mask in the TIMER0 ISR that was messing with the
    indicator LEDs on openclack; resolved.
    Added both key matrix types (dashkey-custom and openclack) as
    conditional compiles
    Conditionally blocked out more LED matrix stuff
    [dashkey.c]
2013-07-26 Added album of photos of the prototype link in the readme.
2013-07-26 Fixed codes for left, down, right arrows. All keymappings work now! : D
    [dashkey.c]
2013-07-26 Added square pads on indicator LED pads.
    [openclack-tkl.kicad_pcb]
2013-08-07 Increased pad distance for BC CT1, prototype was a tight fit.
    [openclack-tkl.kicad_pcb]
2014-01-17 small tweaks for LEDs (temp)
2014-01-17 Added freecad renders
    WIP for now, will be CNC style case and plate for OpenClack design.
    [openclak_case.FCStd]
2014-01-17 update to freecad model
    [openclak_case.FCStd]
2014-01-25 Fixed pin assignment for LED mosfet control
    [dashkey.c]
2014-05-01 Organized project some
    Cleaned up folder structure, edited notes and readme.
    Removed inkscape plots and added fabrication folder
    [acrylic_0.dxf, acrylic_1.dxf, acrylic_2.dxf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]
2016-09-06 new prototype fabrication files
    -Changed old prototype fabrication folder to "prototype a"
    -New "prototype b" folder has laser cut DXF and SVG files. It is the
    same design as before just optimized files for laser cut. Simple 3
    layer type this time.
    [acrylic_0.dxf, acrylic_1.dxf, acrylic_2.dxf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]
2016-09-06 Mistake with mm units in new prototype b fabrication files, fixed
    [openclack-tkl-case-and-plate.dxf]
2020-04-09 Added some photos of prototype.
2020-04-10 Added better PCB image and updated README to show it.
